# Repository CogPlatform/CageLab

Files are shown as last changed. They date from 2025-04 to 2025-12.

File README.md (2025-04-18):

---
title: CageLab
author: Ian Max Andolina
---

# Table of Contents

1. [Introduction](#introduction)
1. [Installation](#installation)
1. [Dependencies](#dependencies)
1. [Usage](#usage)
1. [Parts List](#parts-list)
1. [Architecture](#architecture)
1. [Contributing](#contributing)
1. [License](#license)

# Introduction

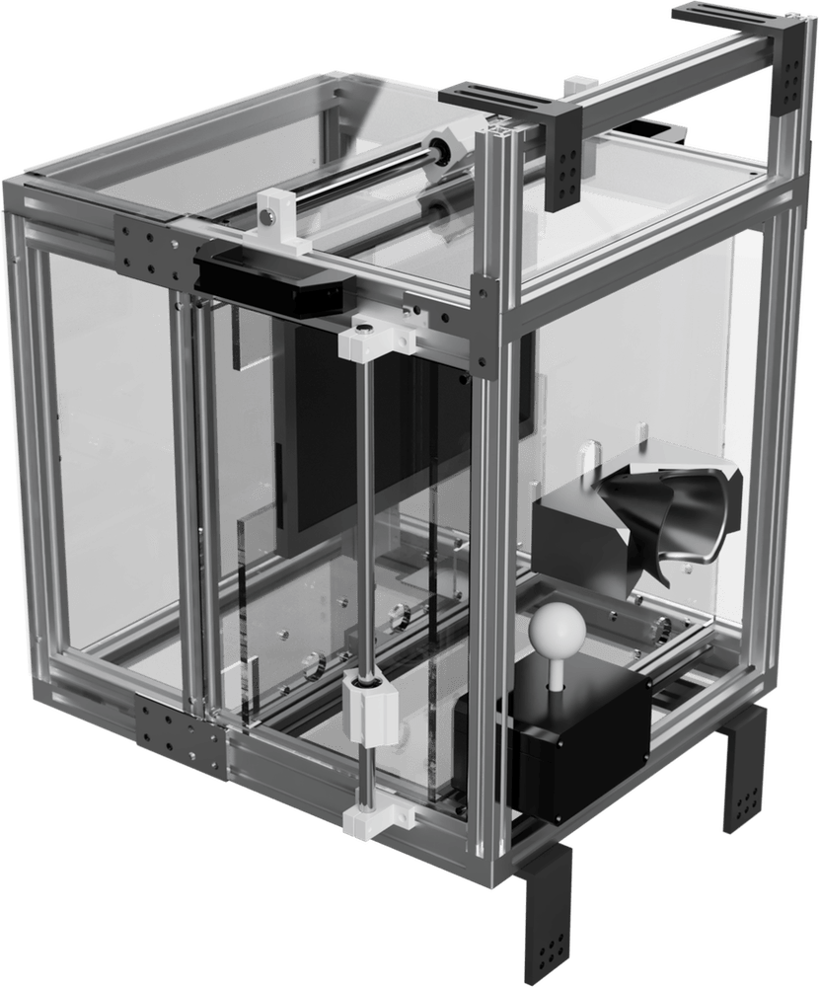
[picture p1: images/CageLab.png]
CageLab Render with Eyetracking and Joystick modules attached


CageLab is a low cost in-cage touchscreen training device that prioritises the following features:

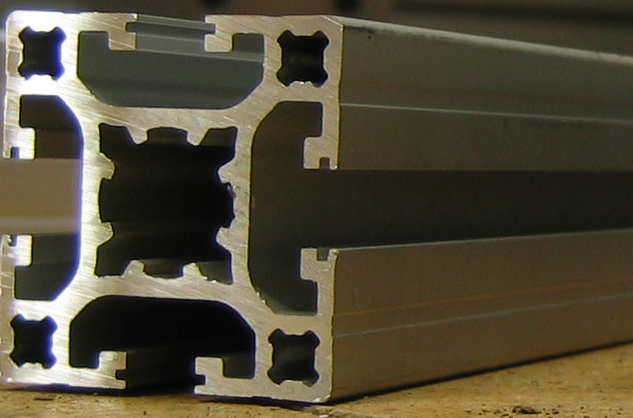
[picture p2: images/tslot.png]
1. **Customisable**: The device should be customisable to suit different facility needs. We employ a modular design using [ T-slot framing](https://en.wikipedia.org/wiki/T-slot_structural_framing) for the shell to allow for easy modification without needing a full workshop.
1. **Scalable**: Integration with the Alyx metadata pipeline ([International Brain Lab, 2023, Nature Methods](https://doi.org/10.1038/s41592-022-01742-6)) to allow for easy management of the data generated by multiple CageLab instances. Each device uploads behavioural data to a central server, which can be accessed and searched by the user through a web interface.
1. **Automatic Training**: Use behavioural shaping stages with an automated staircase to guide subjects to improved behavioural performance with less experimenter intervention.
1. **Low Cost**: CageLab should be affordable for most research labs. We aim to keep the total cost of the device below $400.
1. **Single-enclosure & Battery Operated**: Many animal facilities do not have accesible power outlets near animal housing, or do not want cables or extra trolleys. The device should be self-contained and battery operated. We added a small UPS to enable hot-swapping of batteries.
1. **Open Source**: The device software should be open source and easy to contribute to.
1. **Common Software Path**: The device should be easy to use and maintain; we use [PsychToolbox (PTB)](https://psychtoolbox.org) for easy integration with existing code common in most labs where PTB is prevalent. PTB offers best-in-class experiment timing and a wide range of specialised hardware support.
1. **Modular**: We have the following modules to use with the device:
   - **Fluid Pump**: Peristaltic pump, HID interface and costs about $10.
   - **Food Dispenser**: A pellet dispenser using an arduino driver.
   - **Camera**: A camera to record the animal's behaviour and stream it over the network.
   - **Speaker**: A speaker to play sounds.
1. **Remote Control**: The device must be controllable remotely. We use the fast moonlight remote desktop protocol and server + client protocols where useful.

# Installation and Setup

## Multi-Cage Setup

CageLab is designed to be used in a multi-cage setup. Each CageLab instance is connected to a central Alyz server that manages the data generated by each device. The server is accessible through a web interface that allows the user to search and download the data generated by each device. The experiment control software is run on a remote desktop that is connected to the device through the ZeroMQ client server protocol. The remote desktop allows the user to control the device from a distance and monitor the animal's behaviour through a camera that is connected to the device.

CageLab Multi-Cage Setup

## Hardware

## Software

You need Octave / MATLAB, PTB and the [opticka toolbox](https://github.com/iandol/opticka) installed as dependencies. For remote desktop, you need to install moonlight on the device and the client.

# Dependencies

- [matmoteGO](https://github.com/Ccccraz/matmoteGO.git)
- [cogmote](https://github.com/Ccccraz/cogmote.git)
- [cogmoteGO](https://github.com/Ccccraz/cogmoteGO.git)
- [streaming](https://github.com/Ccccraz/cagelab_streaming.git) Construction in progress
- [PTBSimia](https://github.com/Ccccraz/PTBSimia.git)

# Parts List

# Architecture

## Power supply architecture

### Poe solution

In previous version, we need to use power bank to power the device, but it is limiting the time of use. So we try to use poe to power the device.

> need poe IEEE 802.3bt and 802.3at protocol

> Expermimental feature!!!

> DC HUB was dangeous!!!

```mermaid
---
title: Power supply architecture with poe
---
graph LR
    subgraph Poe Router / Power Supply
    A
    F
    end
    A[IEEE 802.3bt terminal] -->|60 wt| B[poe++ splitter]
    A -->|Net connection| B
    B -->|24v| C[24v to 19v]
    B -->|Net connection| E[Mini PC]
    C -->|19v| D[DC UPS]
    D -->|19v| E
    F[IEEE 802.3at terminal] -->|30 wt| G[poe+ splitter]
    G -->|12v 2.5A MAX| H[DC HUB]
    H -->|12v| I[Pump]
    H -->|12v| J[Display]
    H -->|12v| K[speaker]
    H -->|12v| L[Sensors]
    F -->|Net connection| M@{ icon: "material-symbols:auto-delete"}
    subgraph payload
    E
    I
    J
    K
    L
    end
```

### Power bank solution

```mermaid
---
title: Power supply architecture with power bank
---
graph LR
    subgraph Power Bank / Power Supply
    A[PD power bank]
    E[DC power bank]
    end
    A[PD power bank] --> B[PD to dc]
    B -->|19v| C[DC UPS]
    C -->|19v| D[Mini PC]
    E[DC power bank] -->|12v| F[Pump]
    E -->|12v| G[Display]
    E -->|12v| H[Sensors]
    E -->|12v| I[speaker]
    subgraph payload
    D[Mini PC]
    F[Pump]
    G[Display]
    H[Sensors]
    I[speaker]
    end
```

# Contributing

Please feel free to open issues or pull requests. We are happy to help you get started with CageLab. We are also looking for collaborators to help us improve the device.

# License

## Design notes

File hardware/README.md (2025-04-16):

# Hardware

The hardware modules are designed to be modular and easy to assemble. We use T-slot aluminium framing for the shell to allow for easy modification without needing a full workshop. Both the fluid pump and joystick have a HID interface, allowing them to be used with any computer. The food dispenser is designed to be easy to clean and refill.

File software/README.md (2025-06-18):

# Software Frameworks

## Distributed Architecture
CageLab is designed to run on a distributed architecture, where each CageLab instance runs on a separate machine. This allows for flexibility in hardware selection and enables the use of multiple machines to run different experiments simultaneously. Each CageLab instance can be controlled remotely, allowing for easy management and monitoring of experiments.

Each CageLab runs a middleware called [cogmoteGO](https://github.com/Ccccraz/cogmoteGO), which establishes communication APIs to:

1. Relay command packets from a remote desktop machine to a local running PTB/MATLAB process (could be Octave, Python or any other experiment framework). The messages are JSON encoded and sent using a HTTP POST request and cogmoteGO forwards them over a local ZeroMQ REQ channel to the PTB/MATLAB process.
2. Broadacast data messages from PTB/MATLAB (or other experiment framework) that can be subscribed to by any number of remote machines.

We use the Opticka toolbox for the main experiment control, a high-level wrapper for PsychToolbox. A GUI called `CageLab.mlapp` is provided. The GUI is run on your desktop machine and will send the experiment settings to the CageLab instance. The CageLab device runs a MATLAB service called `theConductor` that receives commands and orchestrates experiments. Each experiment protocol can be run either locally or remotely. We use another app, Puremote, to visualise the subject screen (streamed via mediamtx server), a video feed from the CageLab camera and to plot the broadcast data. 

## Software Components

- **Opticka**: A high-level wrapper for PsychToolbox, used for experiment control.
- **cogmoteGO**: Middleware for communication between remote desktop and local CageLab instance.
- **theConductor**: A MATLAB service that orchestrates experiments on the CageLab instance. Runs CageLab behavioural tasks.
- **CageLab.mlapp**: A GUI for configuring and controlling experiments on the CageLab instance, run on a remote computer.
- **Puremote**: An app for visualising the subject display, video feed from the CageLab camera, and plotting the broadcast data.

## Viewing the Opticka experiment log remotely

**theConductor** is run vis `systemd` and logs are therefore readable using `journalctl`. You can read the log remotely using ssh to login to the Cagelab instance and then running `journalctl --user -f -u theConductor`.

## Data pipeline

We use the [International Brain Lab](https://doi.org/10.1038/s41592-022-01742-6) metadata pipeline to manage the data generated by CageLab instances, which opticka supports without any other dependencies. 

## Remote access

We use Zerotier VPN, SSH and NoMachine or [moonlight](https://moonlight-stream.org) for remote control of the device.

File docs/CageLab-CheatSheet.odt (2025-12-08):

I3 Window Manager: Press WIN to show task bar. WIN+ENTER to open a new terminal. Press WIN+[d] to run a program. Press WIN+SHIFT+[q] to close a window. Press WIN+SHIFT+[e] to exit i3. To move desktop WIN+[1]-[9]. To move an app to a new desktop WIN+Shift+[1]-[9]. To toggle windows as tabs/accordion WIN+Shift+[,] as toggle V/H tiles WIN+Shift+[/] and to float a window WIN+Shift+[.] To resize a floating window WIN+RMB and move it WIN+LMB. To move a window to scrachpad WIN+Shift+[+] and show/hide it WIN+[+].

COMMAND | PURPOSE | NOTES
lsusb | Show list of all connected USB devices
xinput list | Show list of all input devices including touch screen. | Find screen and use ID number to enable / disable
xinput enable # xinput disable # | Enable or disable touch screen or other device, # is the ID number you see in the list
toggleInput enable “ILITEK-TP” toggleInput disable “ILITEK-TP” | Enable or disable touch screen using the touchscreen name
cagelab-reset-code.sh | git reset –hard and pull al repos.
cagelab-reset.sh | Restart cogmoteGO and MATLAB theConductor
cagelab-reset-OBS.sh | Restart mediamtx and OBS
cagelab-stop.sh | Stop all cagelab services
cagelab-start.sh | Start all cagelab services
cagelab-monitor.sh | Show CPU/GPU use alongside cogmoteGO and MATLAB logs
update | Update Code folders and essential software (needs internet)
cagepush -s remote folder | On the control computer push one/many local folders to one/many remote cagelab over the local network | Uses rsync
cagepull -s remote1 -s remote2 | On the control computer pull the data from multiple cagelab systems over local network. | Uses rsync
cagepush-files -s remote app | Push one/many files to one/many cagelab over the local network | Uses scp
`

CageLab Command Cheat Sheet

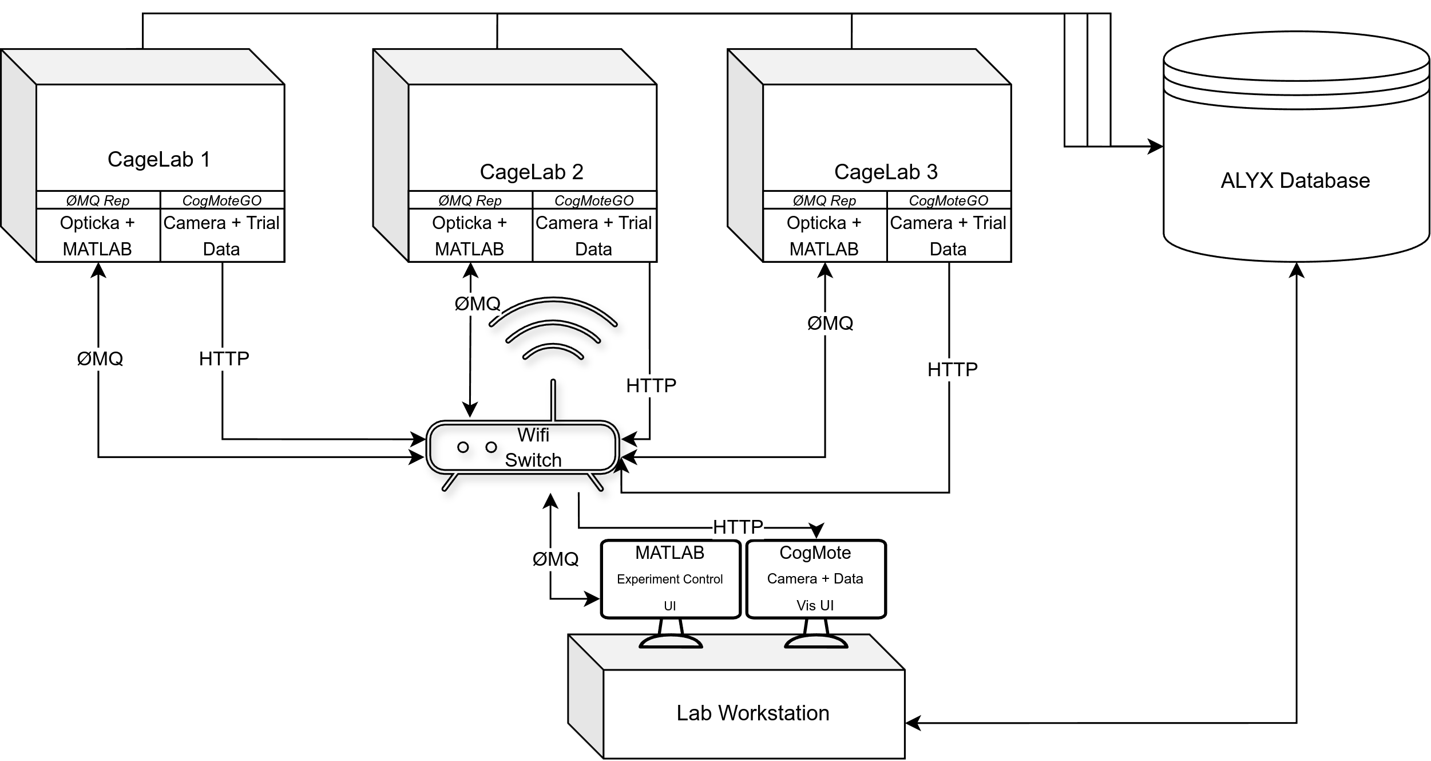
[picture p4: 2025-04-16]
images/CageLab-Network.png

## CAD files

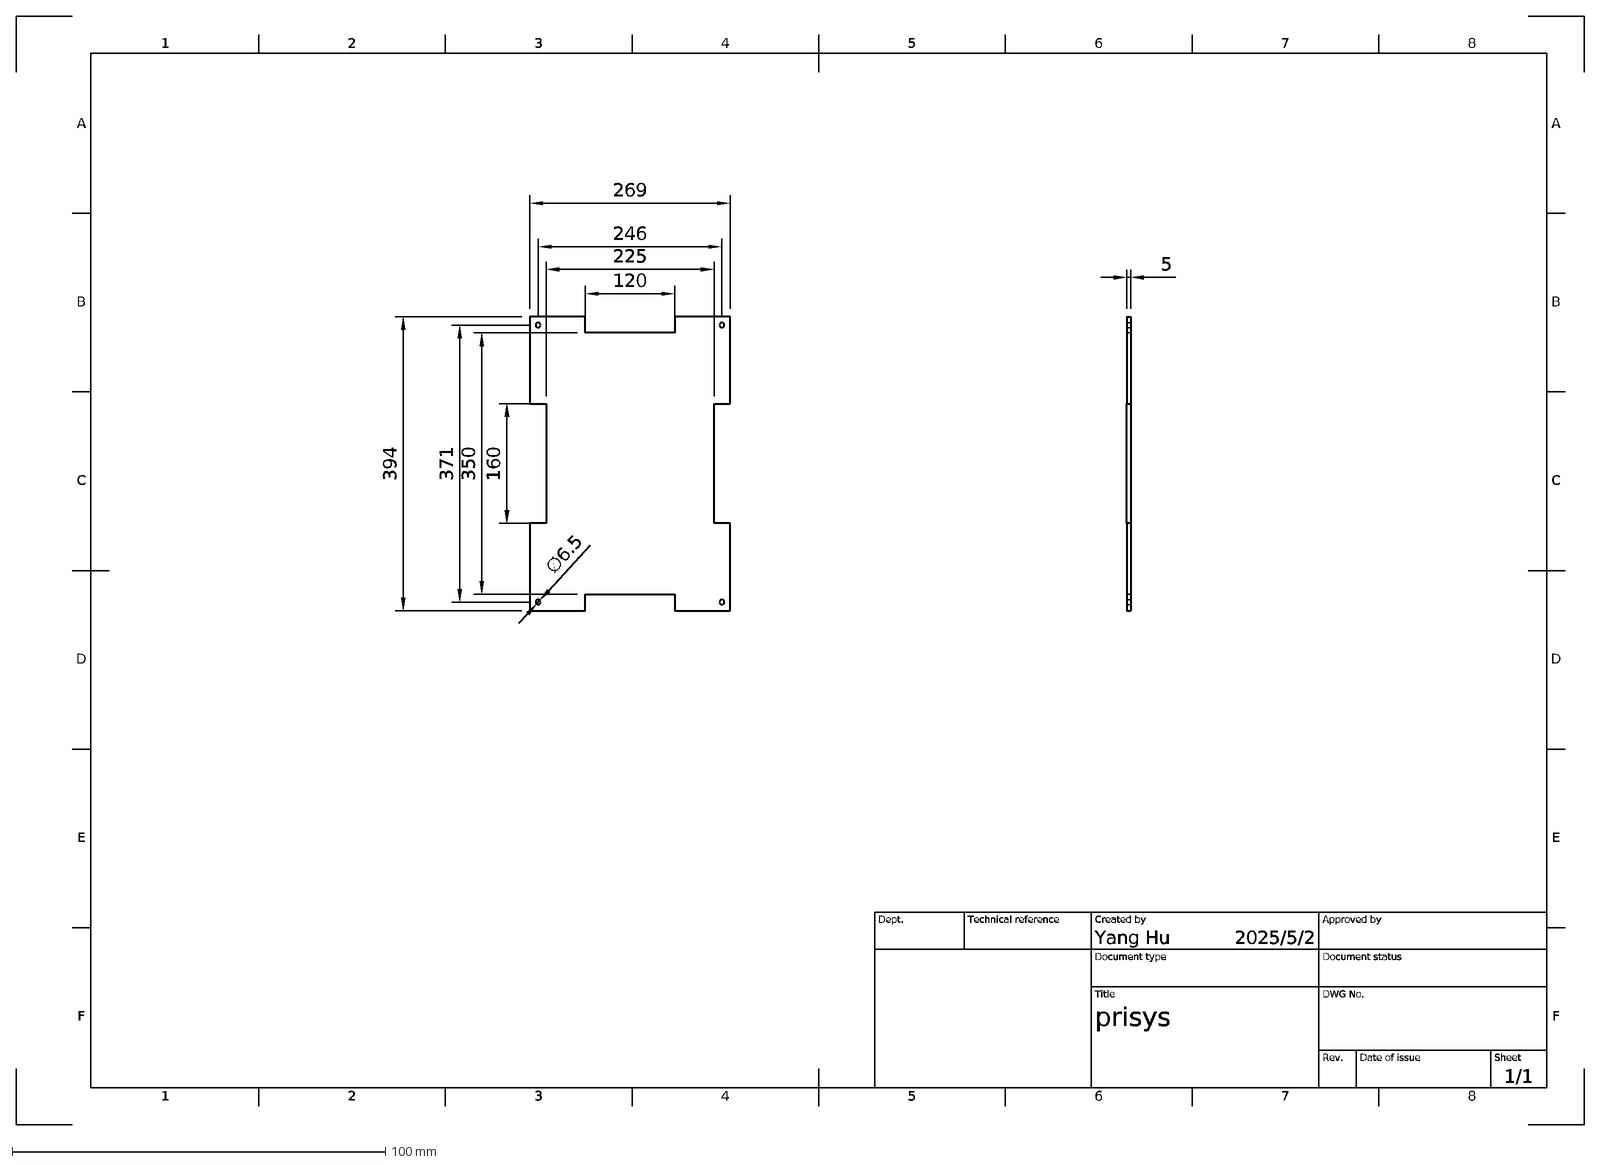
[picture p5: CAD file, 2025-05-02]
manufacture/plate/europe/core_back.dxf
1
A
2
3
4
5
6
7
8
B
C
D
E
F
2025/5/2
1/1
prisys
Yang Hu
Dept.
Technical reference
Created by
Approved by
Document type
Document status
Title
DWG No.
Rev.
Date of issue
Sheet
120
246
269
160
371
394
∅6.5
225
350

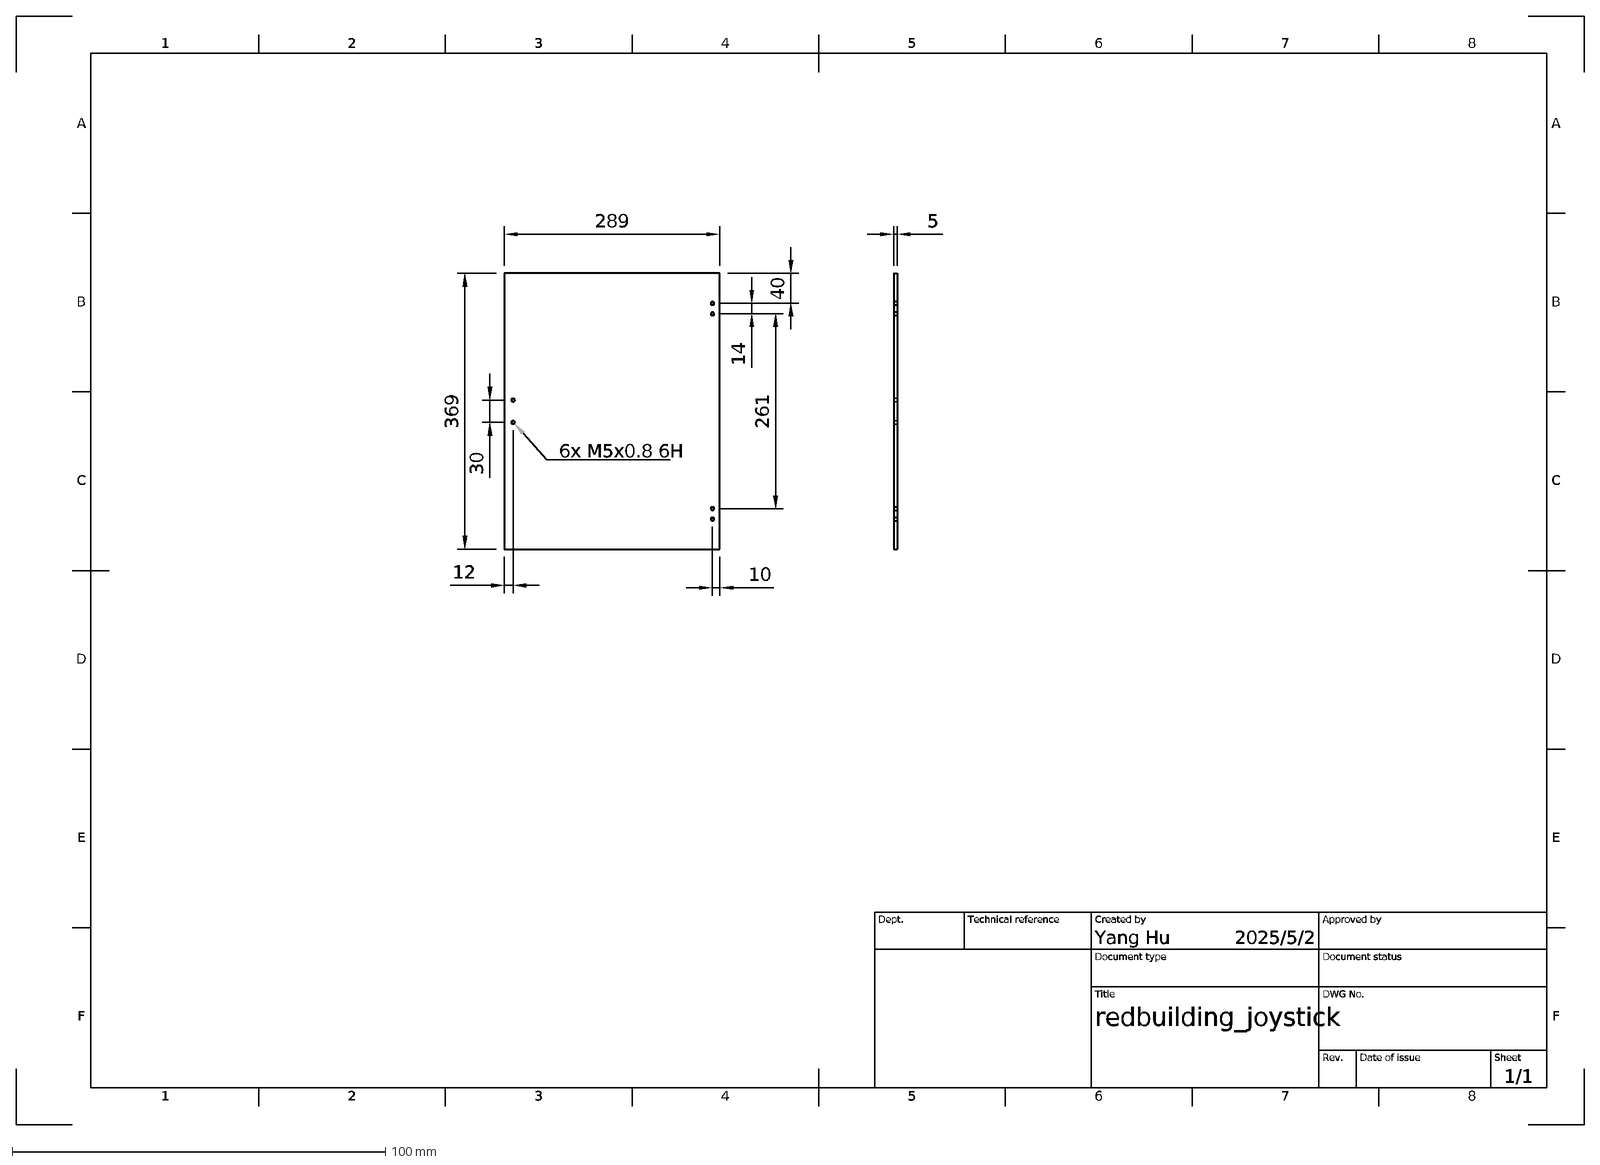
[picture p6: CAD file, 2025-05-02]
manufacture/plate/redbuilding/extra_back.dxf
1
A
2
3
4
5
6
7
8
B
C
D
E
F
2025/5/2
1/1
redbuilding_joystick
Yang Hu
Dept.
Technical reference
Created by
Approved by
Document type
Document status
Title
DWG No.
Rev.
Date of issue
Sheet
289
369
30
14
40
261
6x M5x0.8 6H
12
10

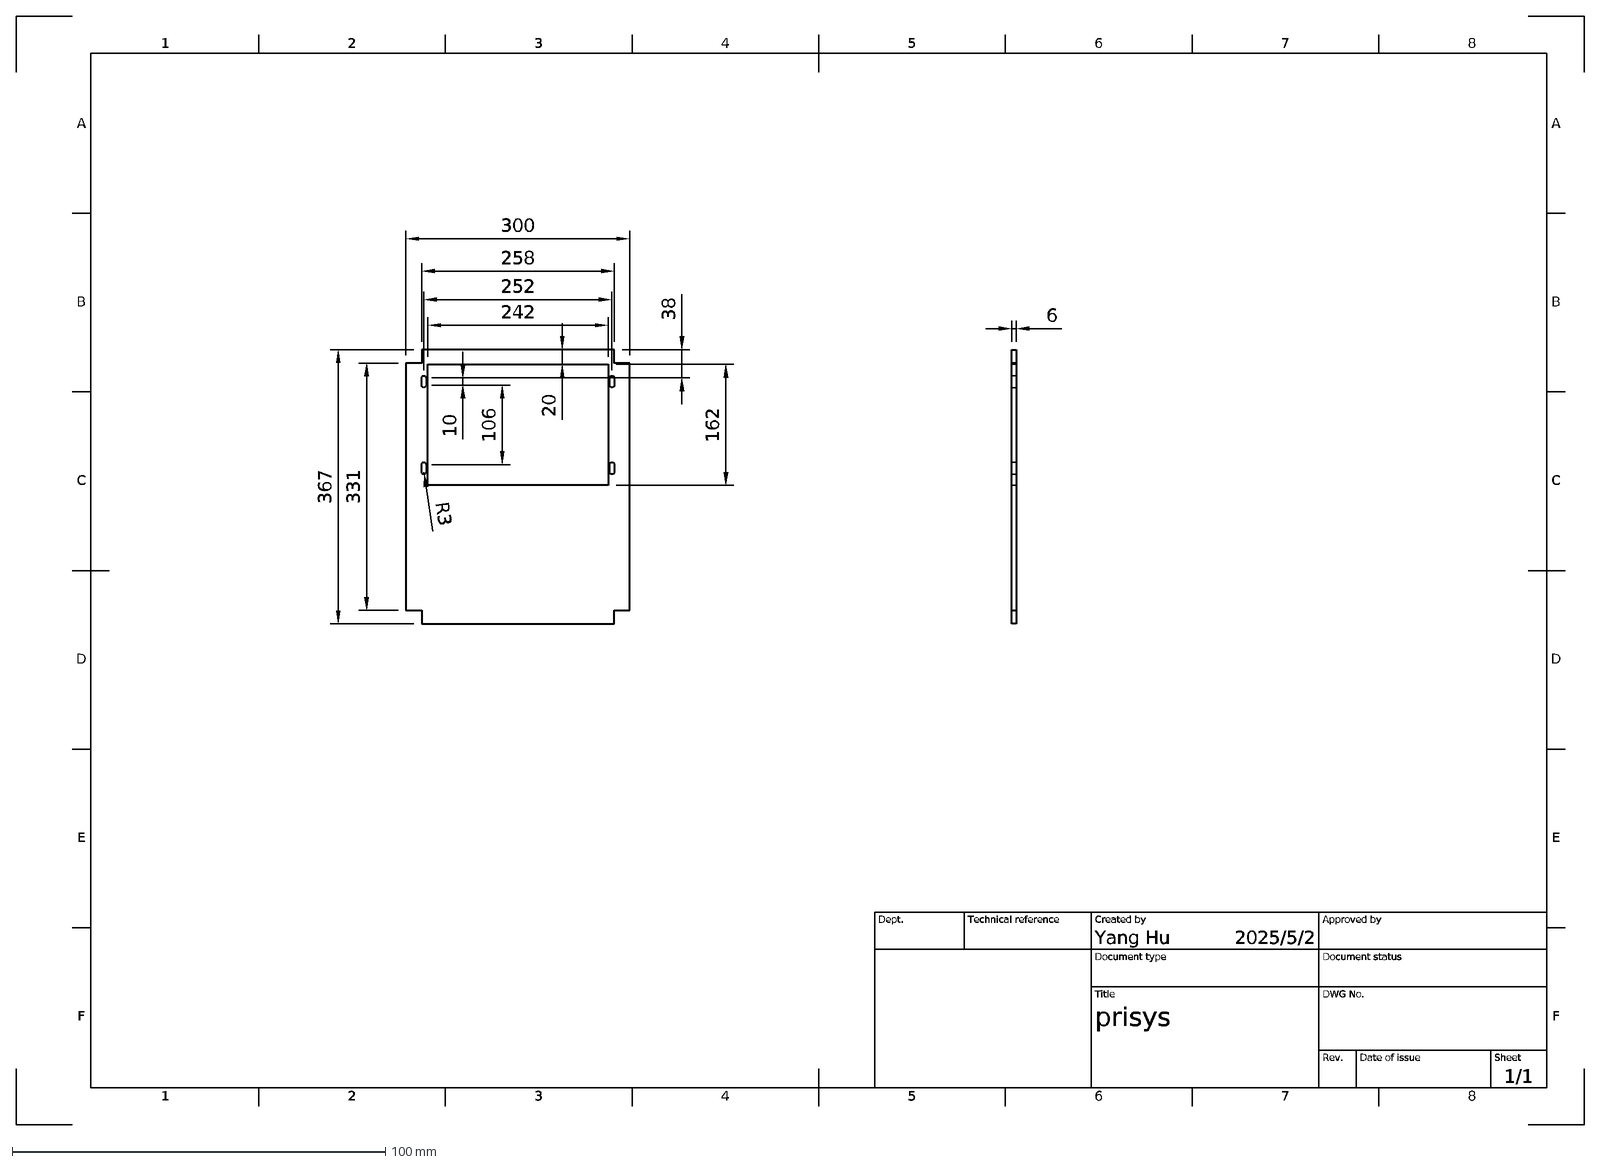
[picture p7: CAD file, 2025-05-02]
manufacture/plate/europe/core_display.dxf
1
A
2
3
4
5
6
7
8
B
C
D
E
F
2025/5/2
1/1
prisys
Yang Hu
Dept.
Technical reference
Created by
Approved by
Document type
Document status
Title
DWG No.
Rev.
Date of issue
Sheet
242
252
258
300
331
367
10
106
38
162
R3
20

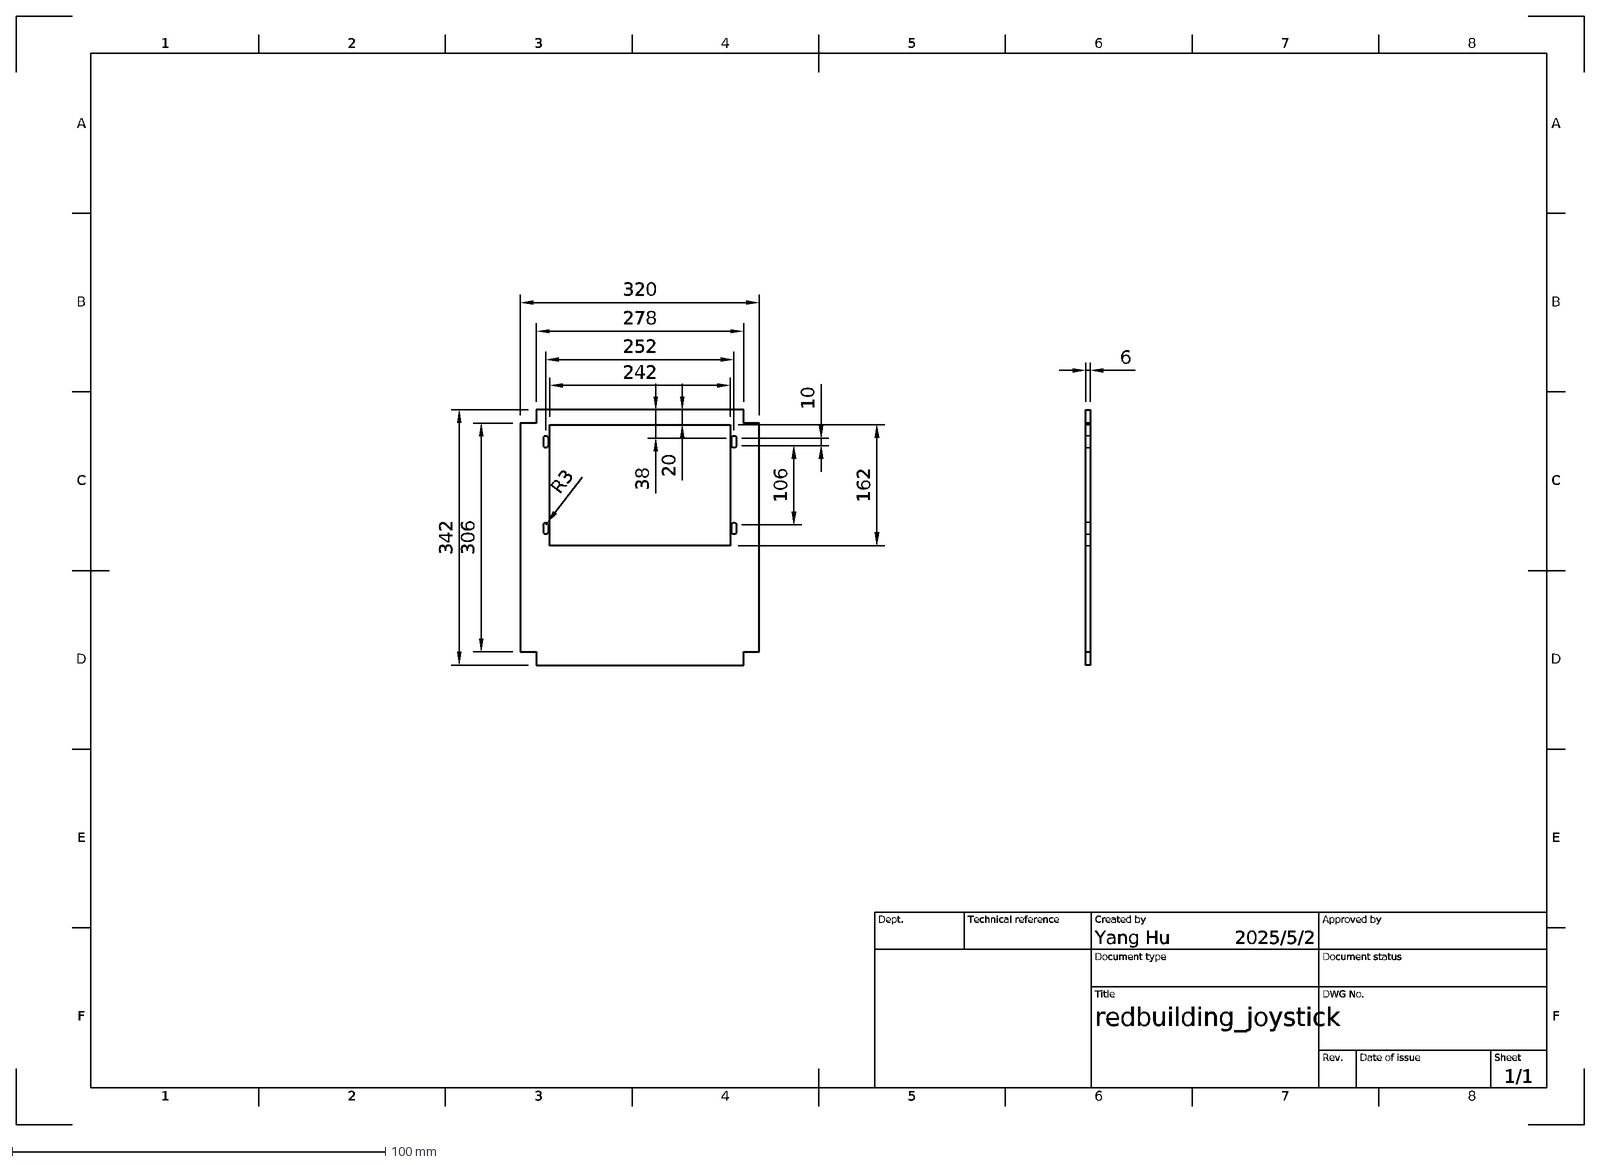
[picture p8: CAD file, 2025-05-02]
manufacture/plate/redbuilding/core_display.dxf
1
A
2
3
4
5
6
7
8
B
C
D
E
F
2025/5/2
1/1
redbuilding_joystick
Yang Hu
Dept.
Technical reference
Created by
Approved by
Document type
Document status
Title
DWG No.
Rev.
Date of issue
Sheet
242
252
278
320
306
342
106
10
162
R3
38
20

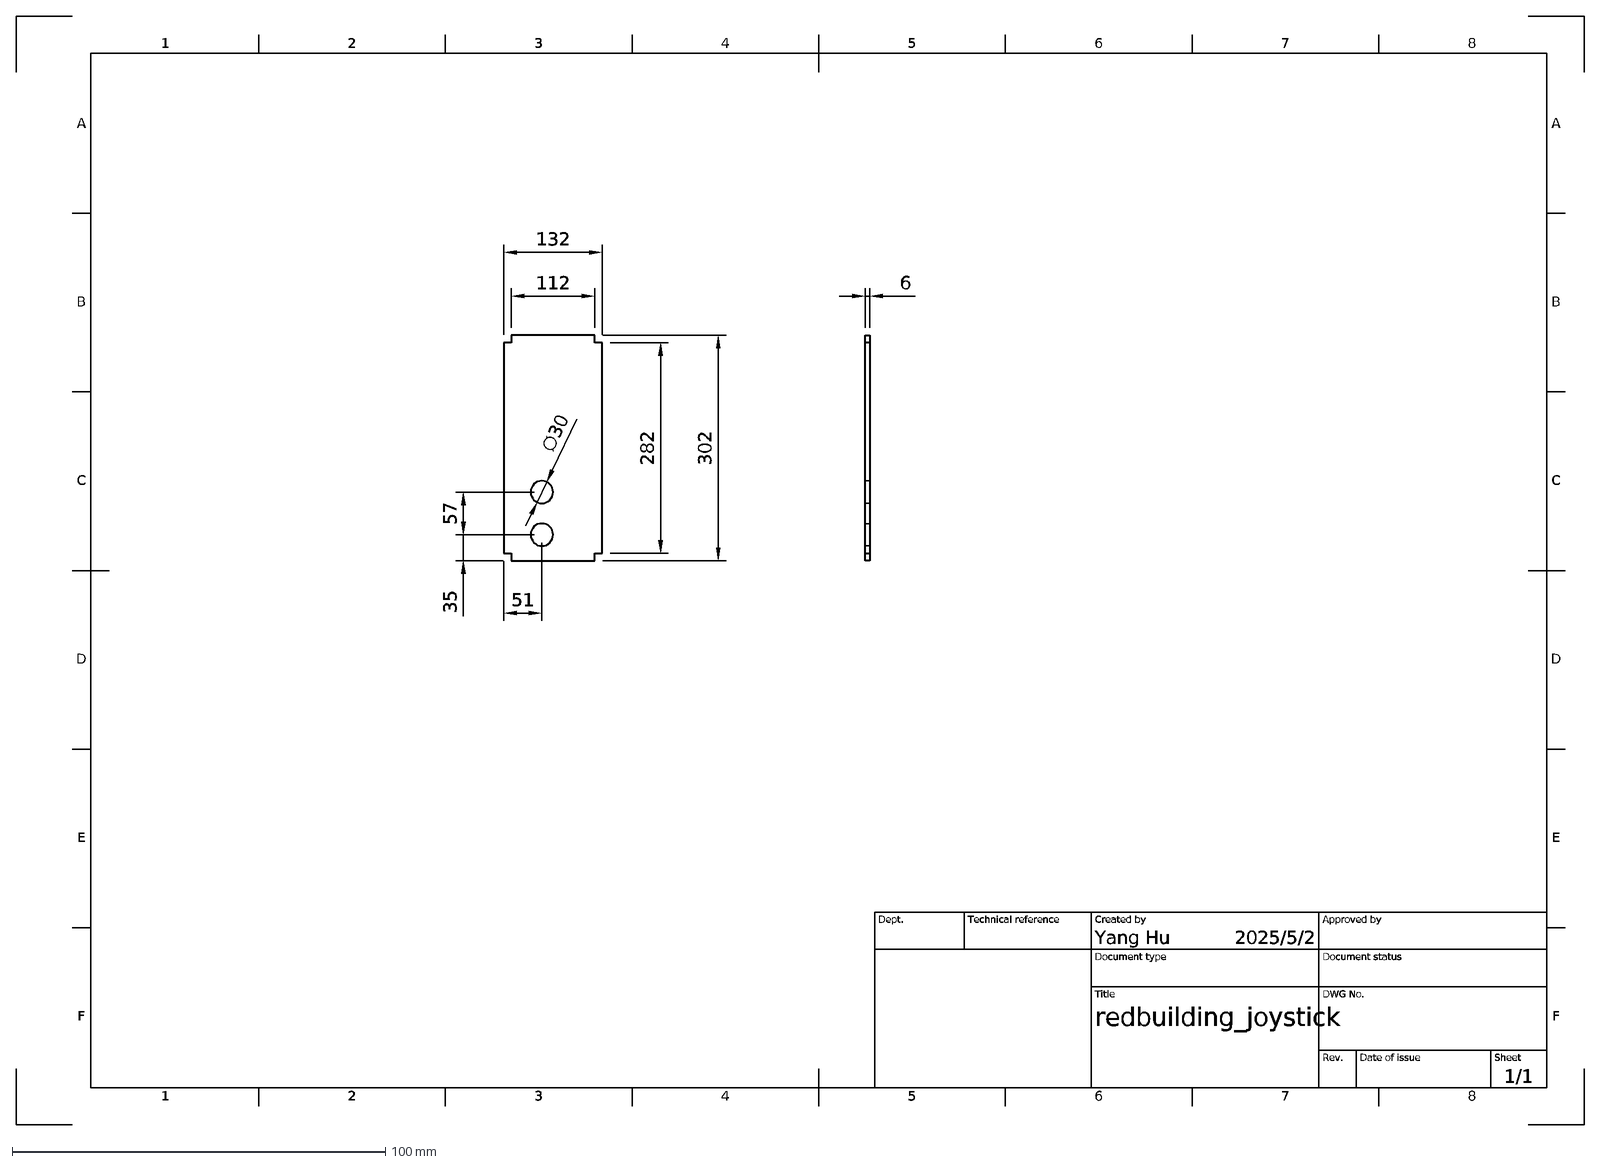
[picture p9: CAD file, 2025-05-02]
manufacture/plate/europe/extra_bottom.dxf
1
A
2
3
4
5
6
7
8
B
C
D
E
F
2025/5/2
1/1
redbuilding_joystick
Yang Hu
Dept.
Technical reference
Created by
Approved by
Document type
Document status
Title
DWG No.
Rev.
Date of issue
Sheet
112
132
57
35
282
302
∅30
51

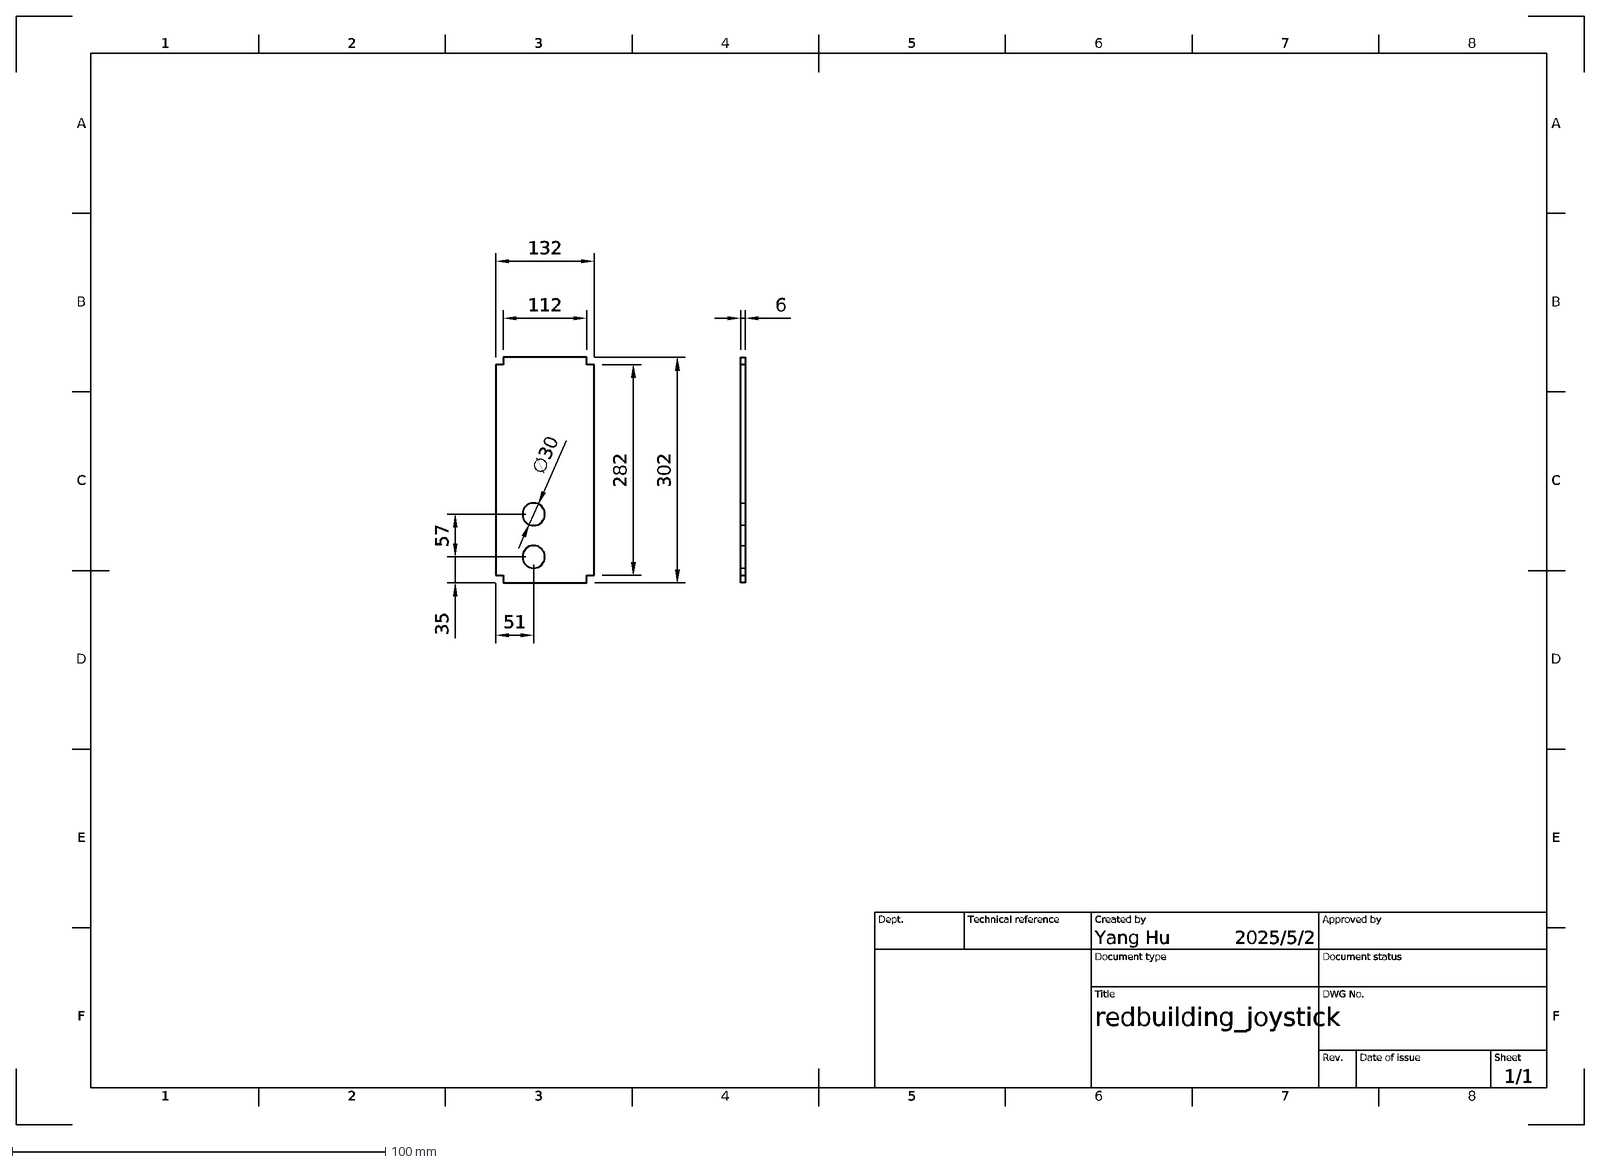
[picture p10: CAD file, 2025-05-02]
manufacture/plate/redbuilding/extra_bottom.dxf
1
A
2
3
4
5
6
7
8
B
C
D
E
F
2025/5/2
1/1
redbuilding_joystick
Yang Hu
Dept.
Technical reference
Created by
Approved by
Document type
Document status
Title
DWG No.
Rev.
Date of issue
Sheet
112
132
282
302
35
57
∅30
51

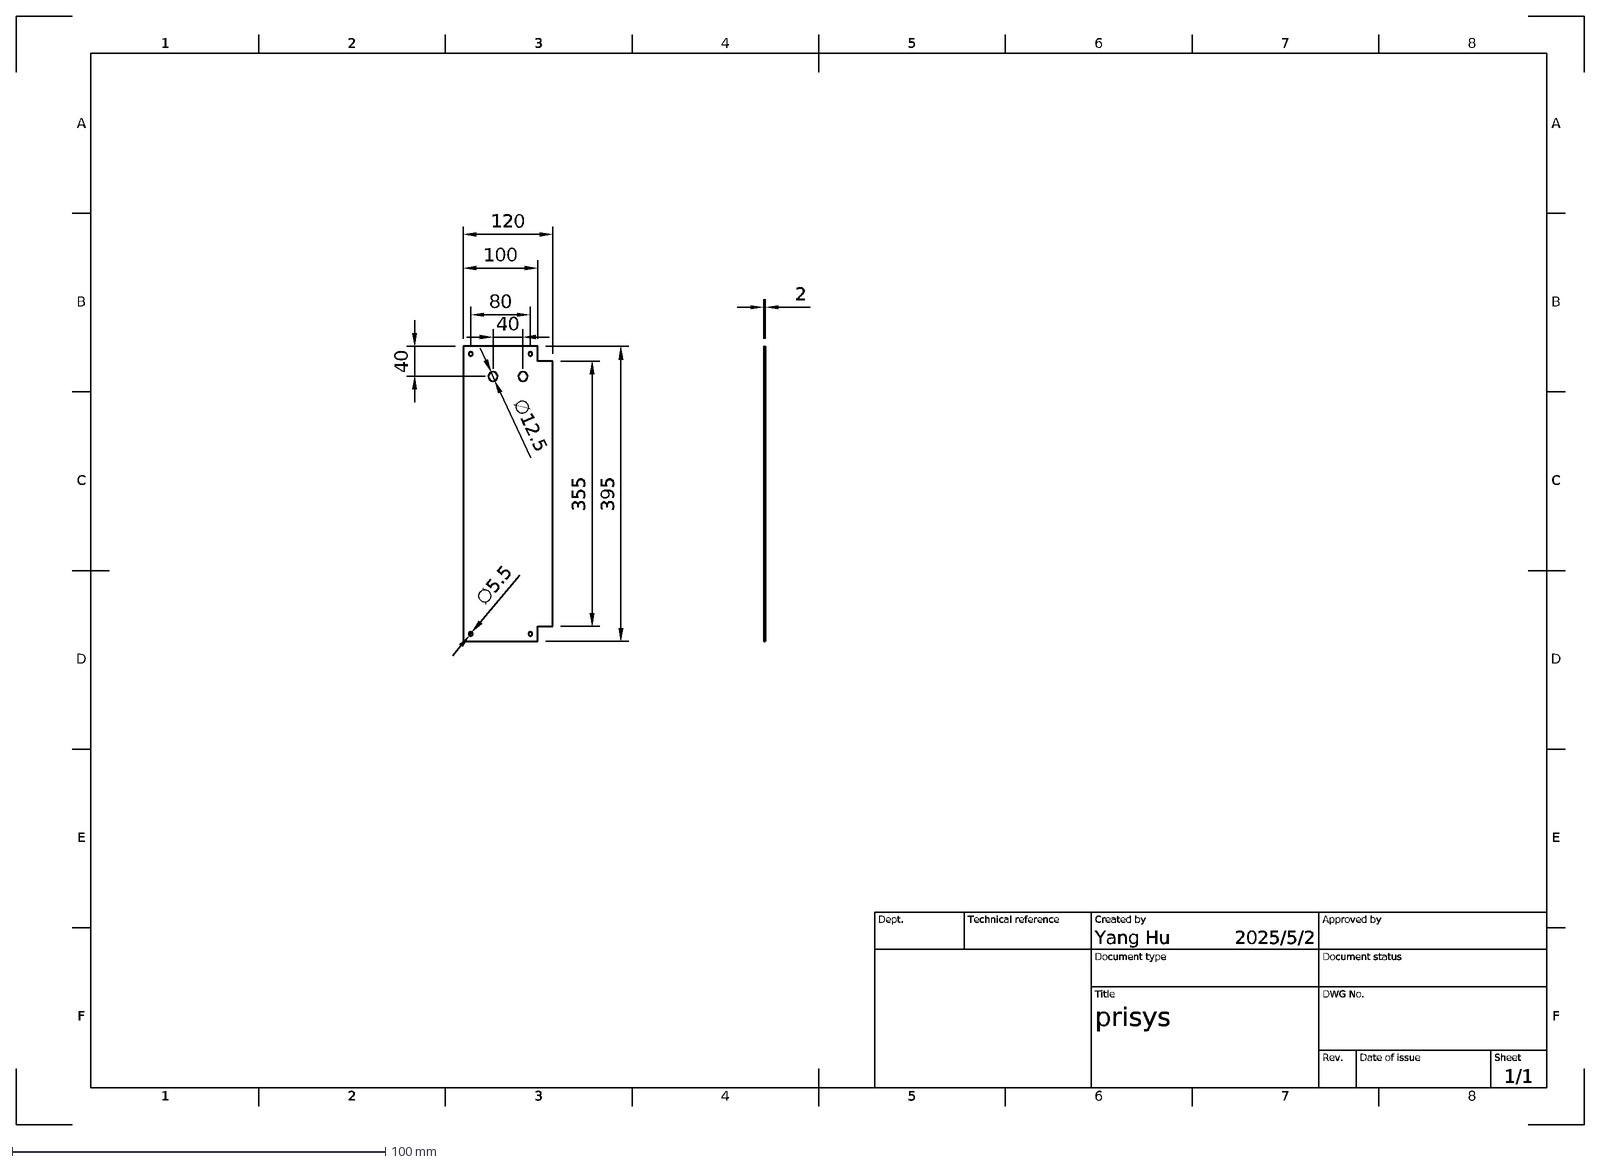
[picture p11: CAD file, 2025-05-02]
manufacture/plate/europe/extra_side.dxf
1
A
2
3
4
5
6
7
8
B
C
D
E
F
2025/5/2
1/1
prisys
Yang Hu
Dept.
Technical reference
Created by
Approved by
Document type
Document status
Title
DWG No.
Rev.
Date of issue
Sheet
40
80
100
120
355
395
∅5.5
∅12.5

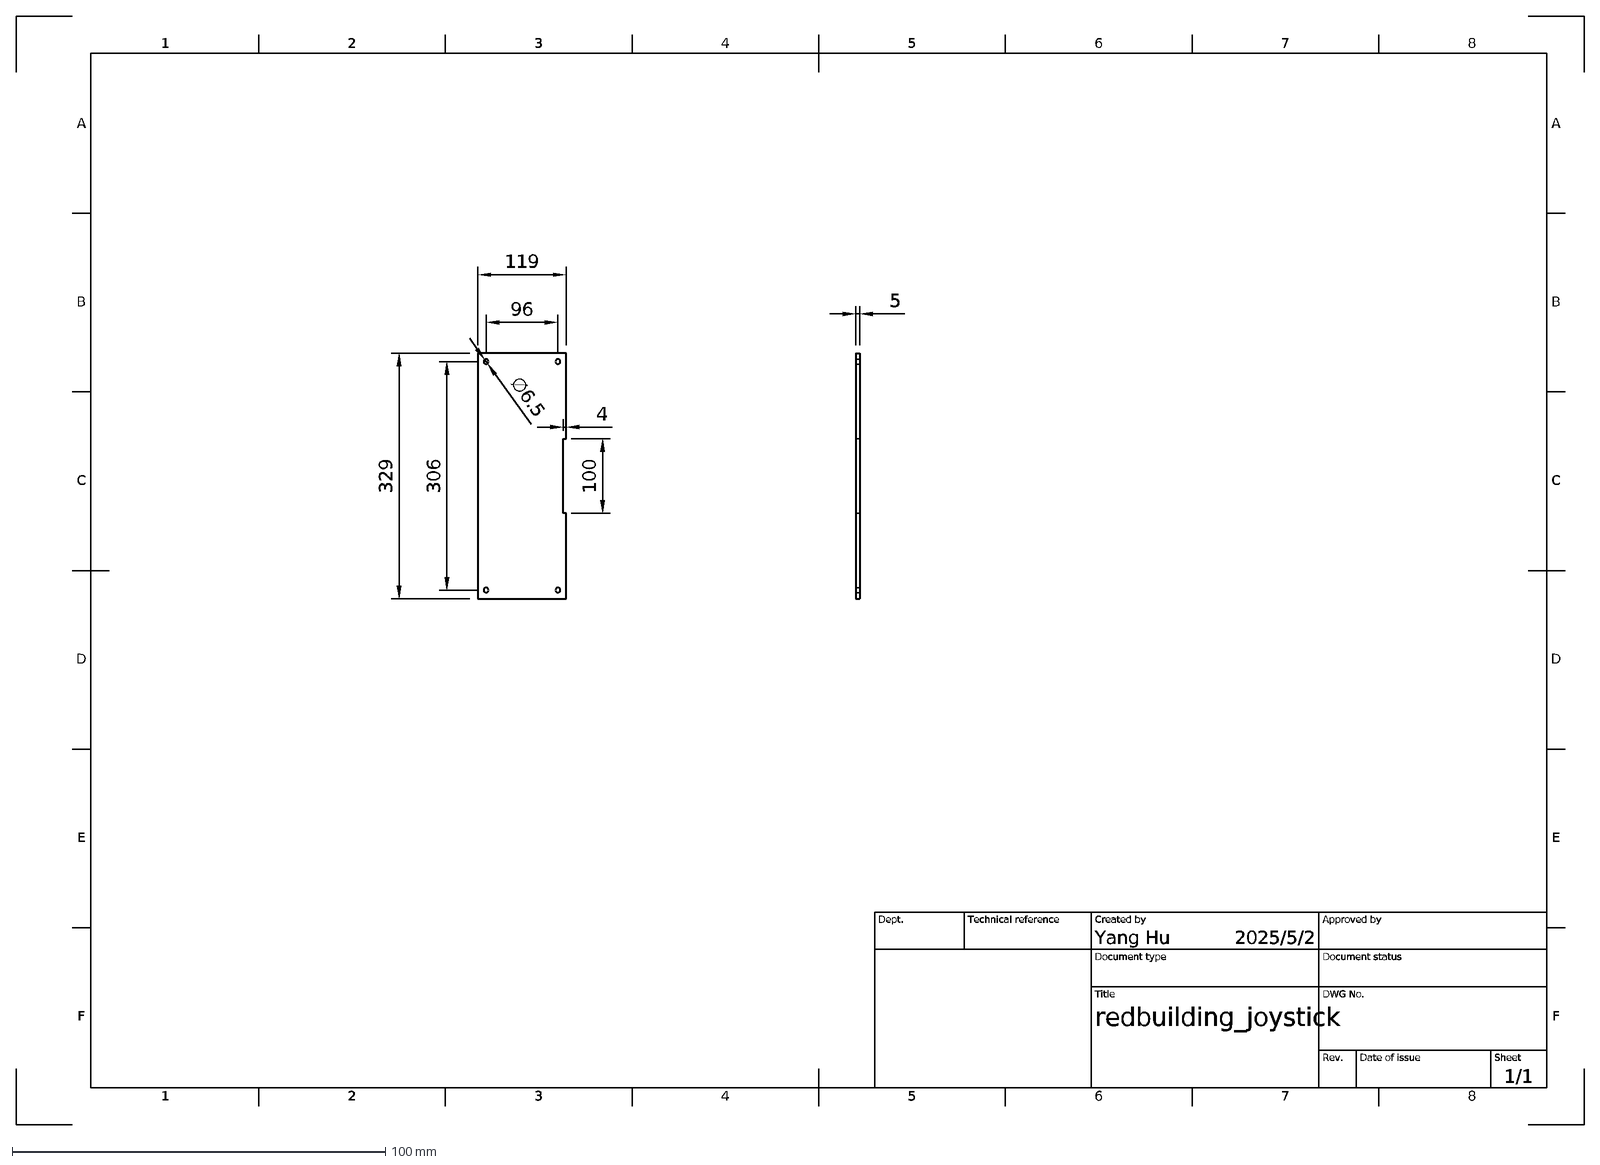
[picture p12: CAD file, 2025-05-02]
manufacture/plate/redbuilding/core_side.dxf
1
A
2
3
4
5
6
7
8
B
C
D
E
F
2025/5/2
1/1
redbuilding_joystick
Yang Hu
Dept.
Technical reference
Created by
Approved by
Document type
Document status
Title
DWG No.
Rev.
Date of issue
Sheet
96
119
306
329
100
∅6.5

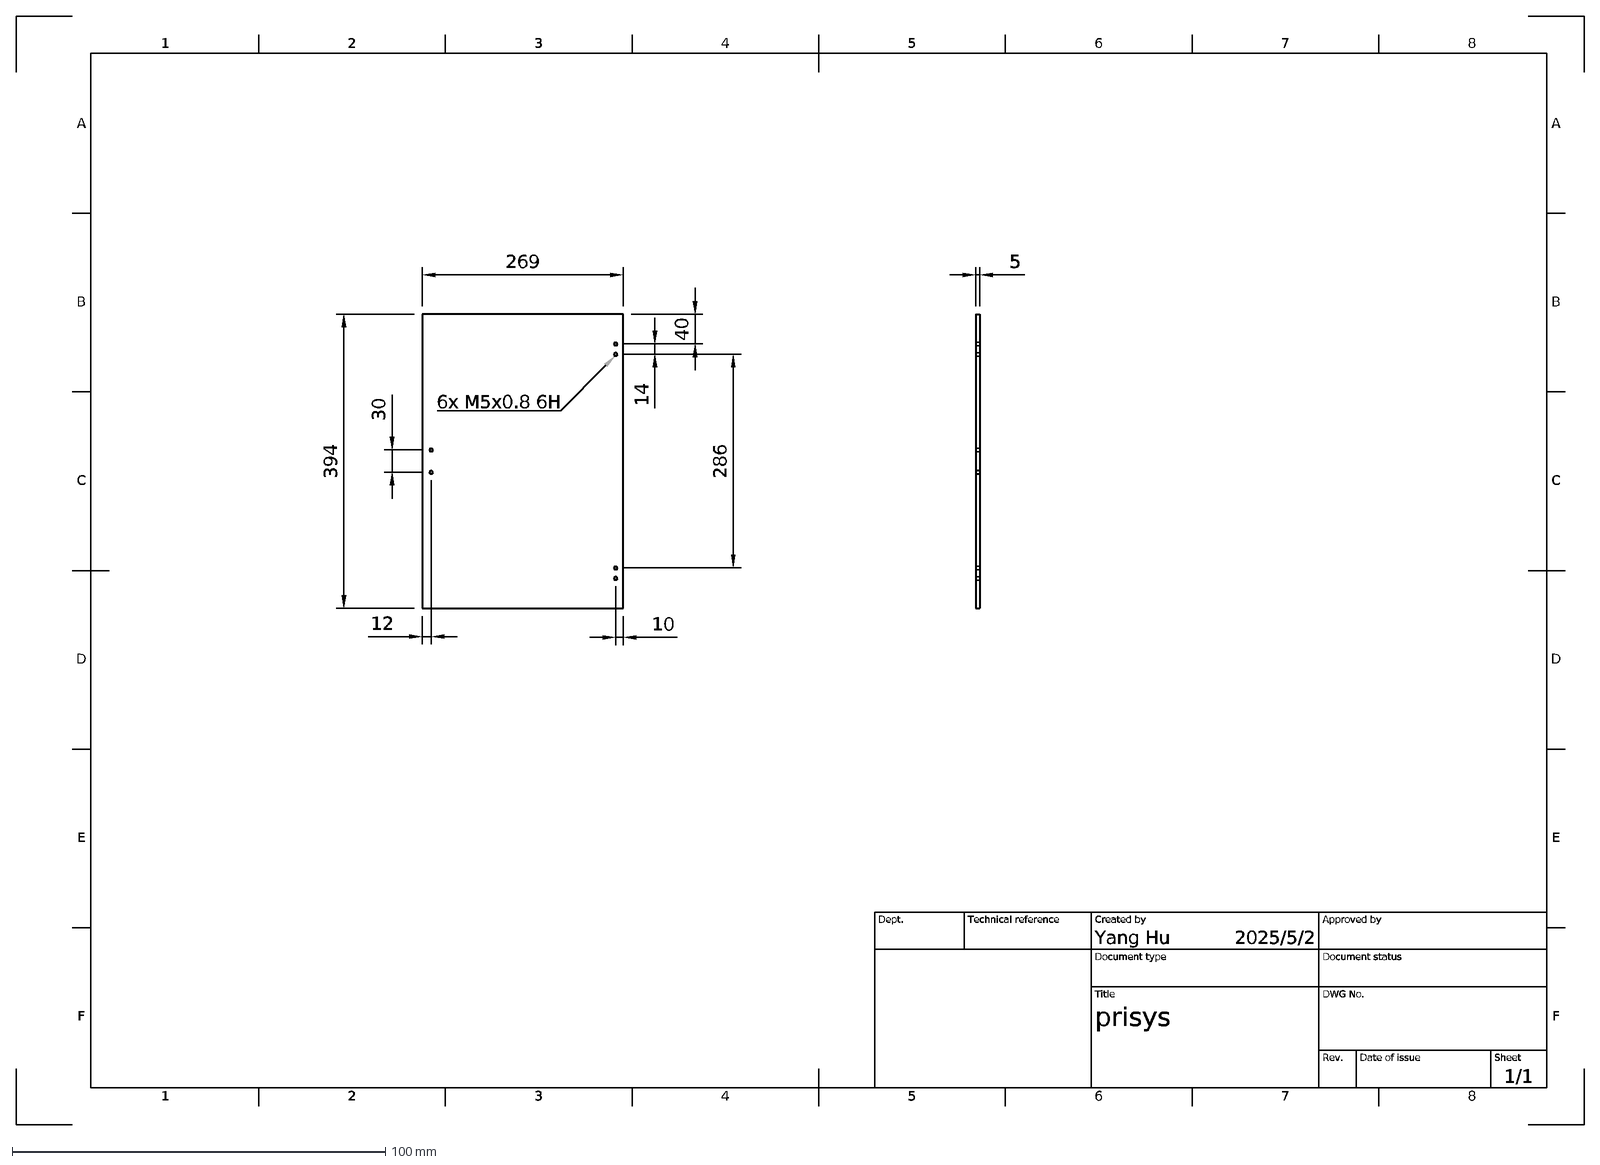
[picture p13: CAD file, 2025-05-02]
manufacture/plate/europe/extra_back.dxf
1
A
2
3
4
5
6
7
8
B
C
D
E
F
2025/5/2
1/1
prisys
Yang Hu
Dept.
Technical reference
Created by
Approved by
Document type
Document status
Title
DWG No.
Rev.
Date of issue
Sheet
269
14
40
286
30
394
6x M5x0.8 6H
12
10

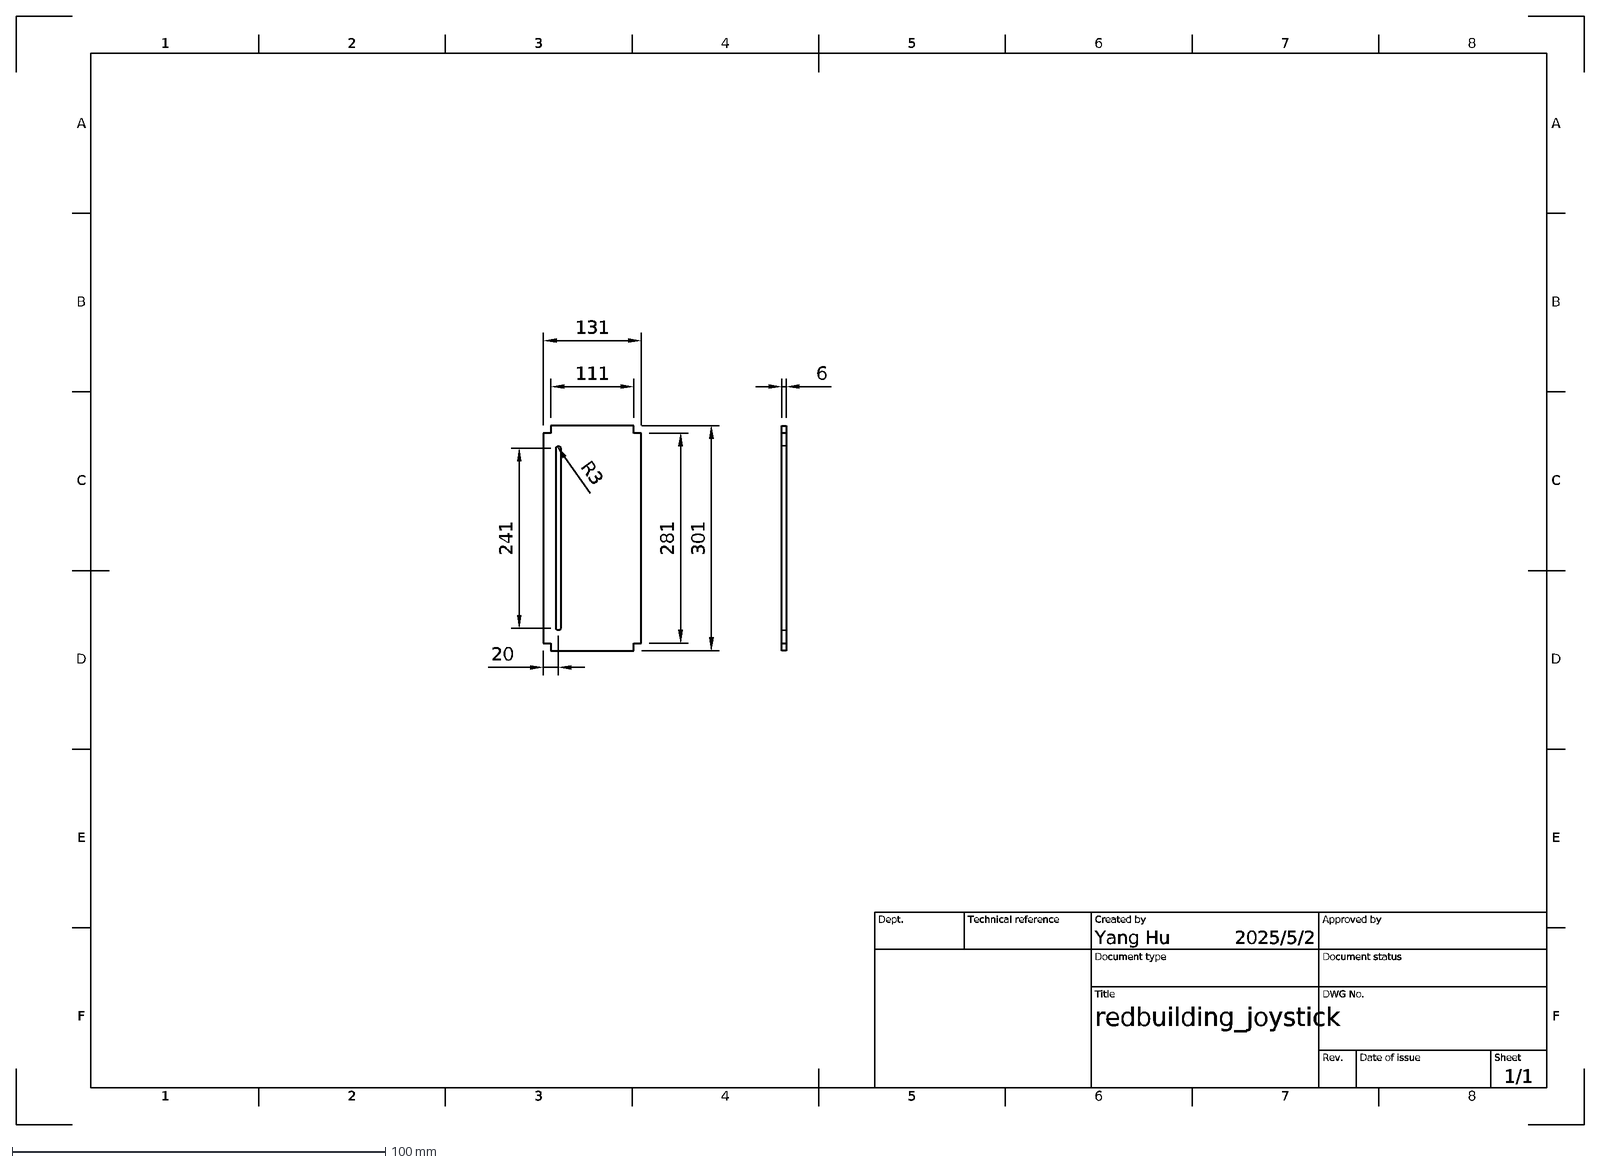
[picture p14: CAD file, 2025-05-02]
manufacture/plate/redbuilding/core_bottom.dxf
1
A
2
3
4
5
6
7
8
B
C
D
E
F
2025/5/2
1/1
redbuilding_joystick
Yang Hu
Dept.
Technical reference
Created by
Approved by
Document type
Document status
Title
DWG No.
Rev.
Date of issue
Sheet
111
131
241
R3
281
301
20

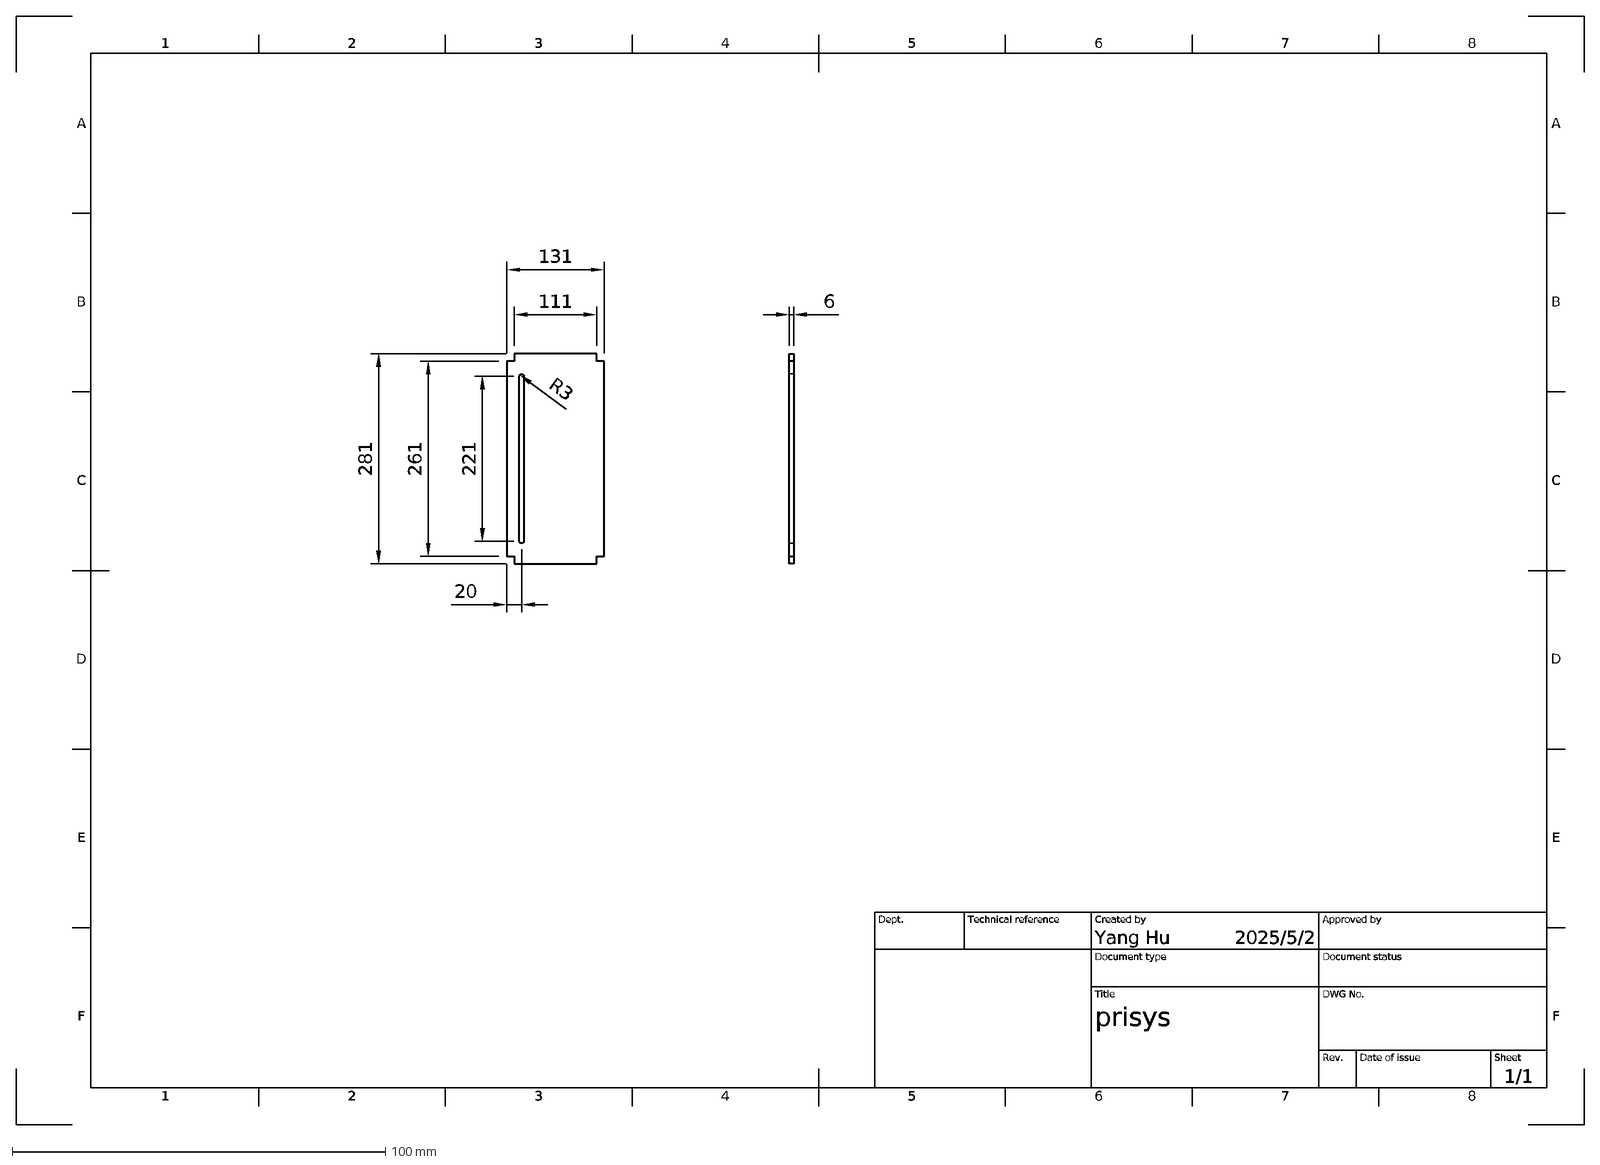
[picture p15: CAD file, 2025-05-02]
manufacture/plate/europe/core_bottom.dxf
1
A
2
3
4
5
6
7
8
B
C
D
E
F
2025/5/2
1/1
prisys
Yang Hu
Dept.
Technical reference
Created by
Approved by
Document type
Document status
Title
DWG No.
Rev.
Date of issue
Sheet
111
131
221
261
281
R3
20

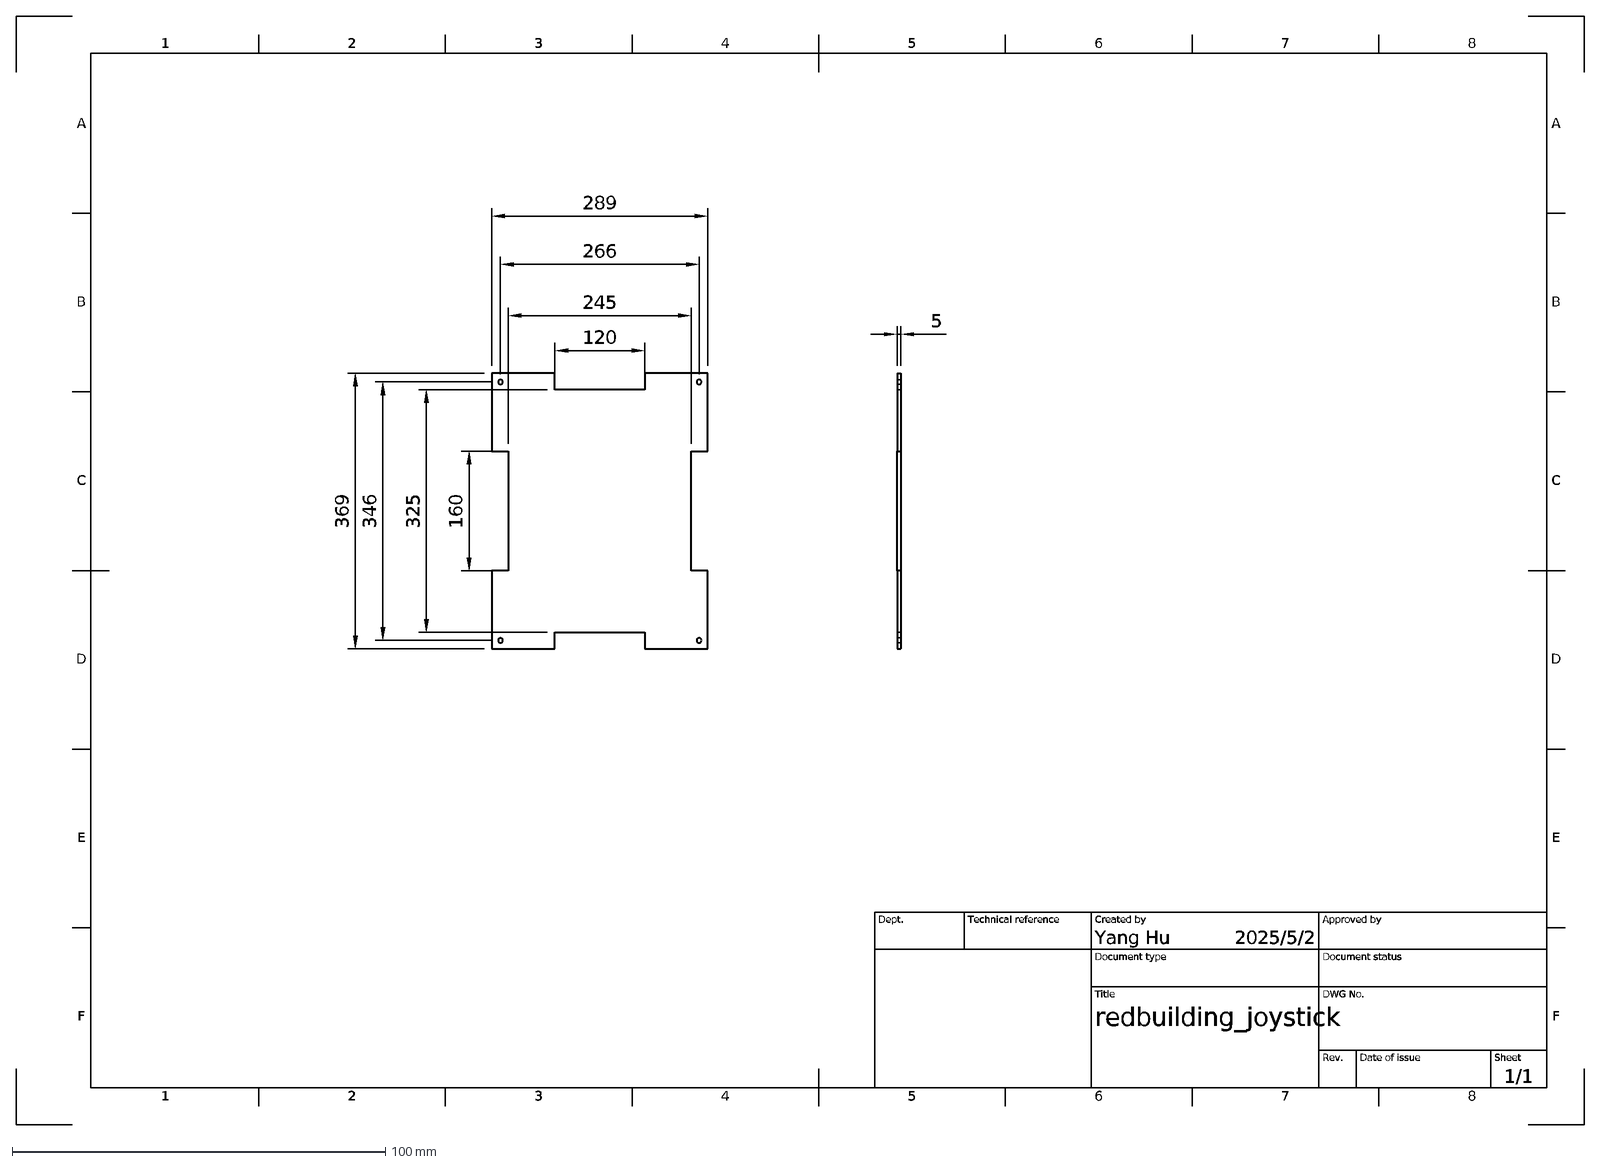
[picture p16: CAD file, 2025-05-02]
manufacture/plate/redbuilding/core_back.dxf
1
A
2
3
4
5
6
7
8
B
C
D
E
F
2025/5/2
1/1
redbuilding_joystick
Yang Hu
Dept.
Technical reference
Created by
Approved by
Document type
Document status
Title
DWG No.
Rev.
Date of issue
Sheet
120
245
266
289
160
325
346
369

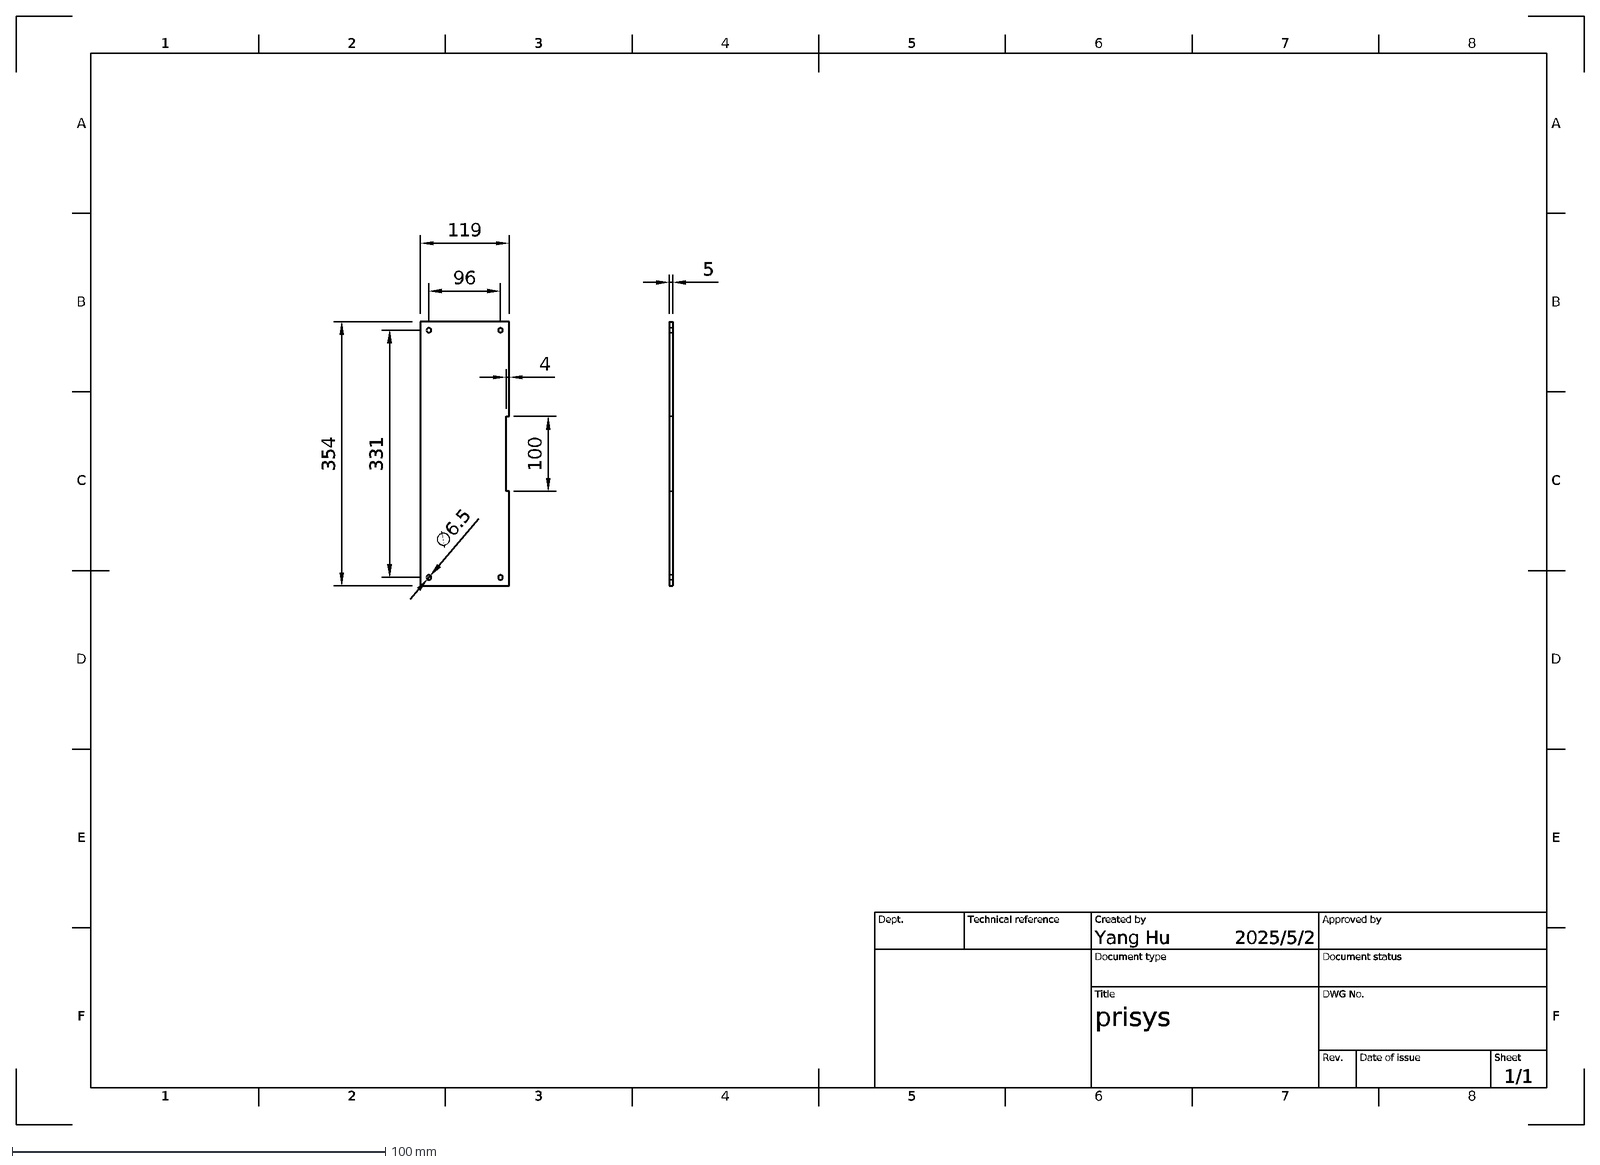
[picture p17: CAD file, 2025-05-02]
manufacture/plate/europe/core_side.dxf
1
A
2
3
4
5
6
7
8
B
C
D
E
F
2025/5/2
1/1
prisys
Yang Hu
Dept.
Technical reference
Created by
Approved by
Document type
Document status
Title
DWG No.
Rev.
Date of issue
Sheet
96
119
331
354
100
∅6.5

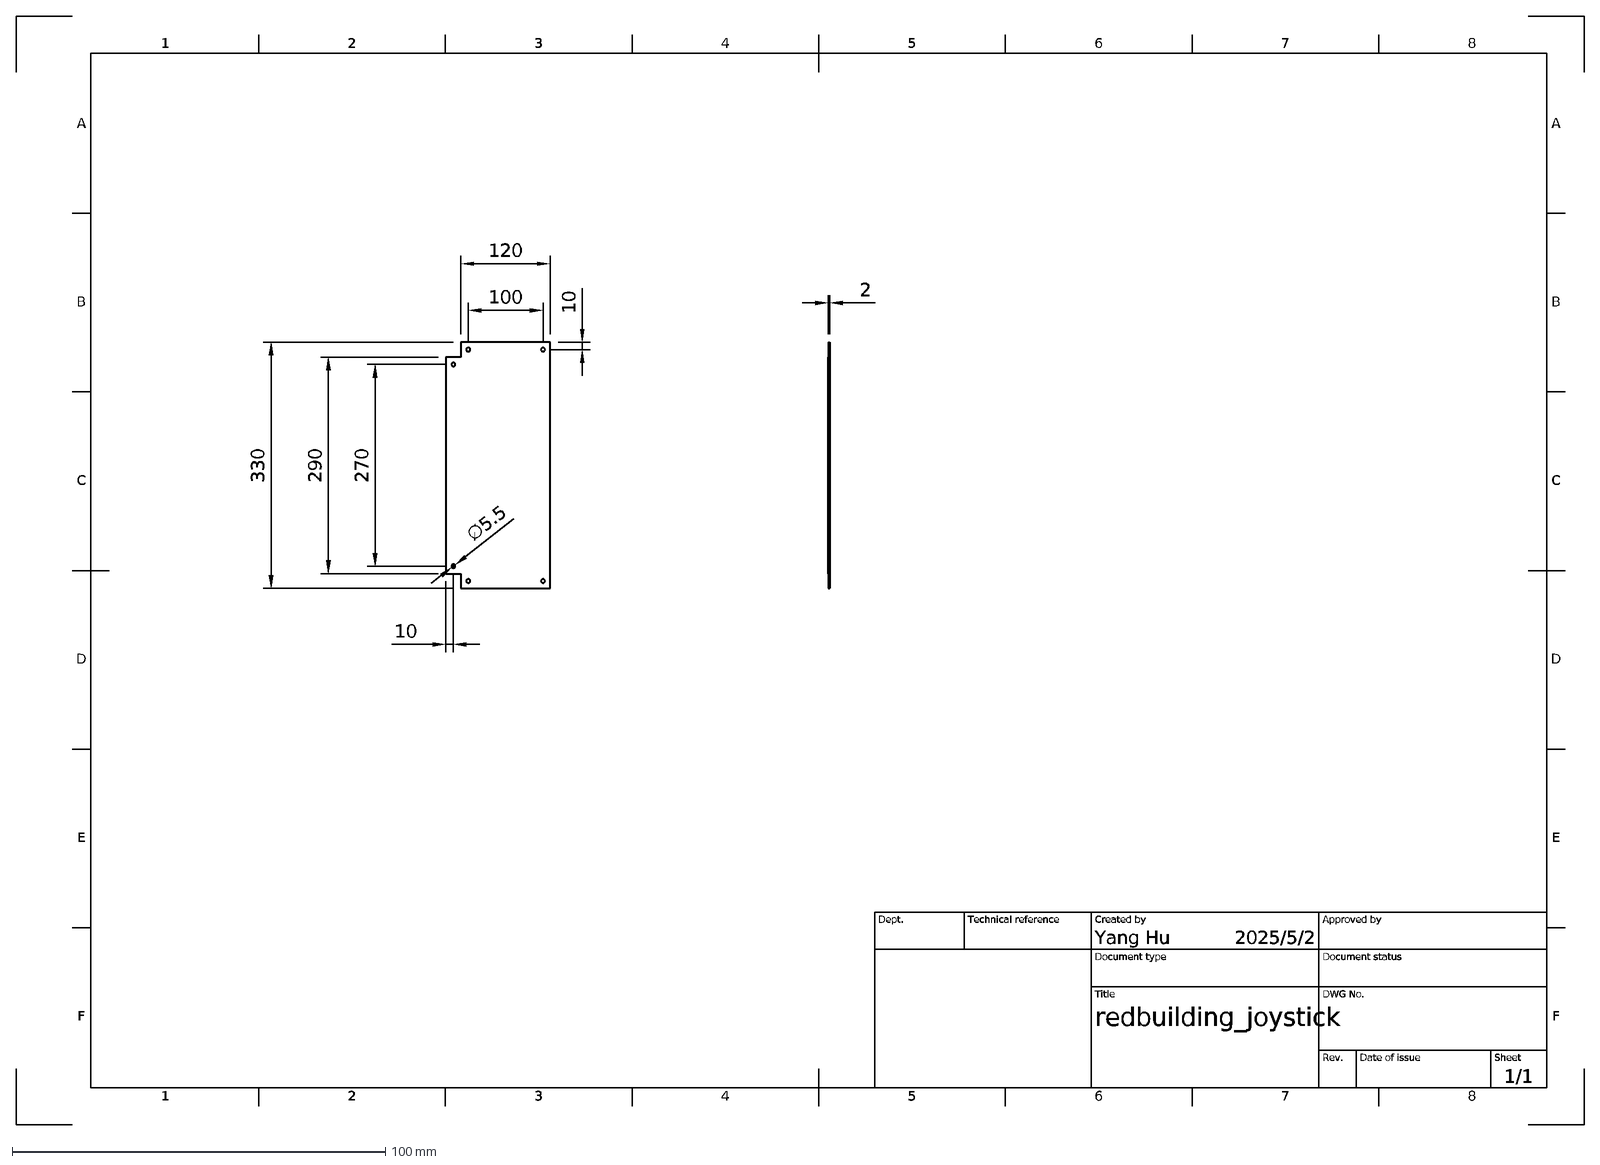
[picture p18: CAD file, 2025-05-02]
manufacture/plate/redbuilding/extra_top.dxf
1
A
2
3
4
5
6
7
8
B
C
D
E
F
2025/5/2
1/1
redbuilding_joystick
Yang Hu
Dept.
Technical reference
Created by
Approved by
Document type
Document status
Title
DWG No.
Rev.
Date of issue
Sheet
100
120
10
270
290
330
∅5.5

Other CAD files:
manufacture/plate/europe/core_top.dxf
manufacture/plate/redbuilding/core_top.dxf
manufacture/plate/europe/display.dxf
manufacture/plate/redbuilding/extra_side.dxf
manufacture/plate/europe/extra_top.dxf
manufacture/plate/redbuilding/display_holder.dxf
manufacture/plate/redbuilding/joystick_holder.dxf
manufacture/plate/redbuilding/redbuilding_joystick_holder.dxf

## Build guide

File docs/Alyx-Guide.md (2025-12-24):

# How to Use Alyx with CageLab

Alyx is an experiment database made by International Brain Lab. While alyx is mostly focused on neuroscience tasks in mice, it can be generalised to other species as it supports generic JSON fields, and the core structure across species is more similar that the differences anyway. We use TWO services:

* Alyx database — register subjects, labs, experimenters, projects and tasks; each time a session is run record the experiment metadata and link to the binary experiment files.
* AWS/S3 data store ([Minio](https://minio.org) server) — copy raw binary and text experiment files saved by each session linked to the Alyx session metadata. Searching in Alyx can recover the files saved in the S3 data store.

------

In the CageLab GUI there are two main interactions with Alyx:

1) Login / query the database. Not linked to an experiment session.
2) Setup session data and enable CageLbb to add the session to the database. THe session is added by the remote system, not the control computer.

# BEFORE STARTING: Setting up the Database

> [!IMPORTANT] 
> You **MUST** ensure the Alyx database is setup with the core items you will use to run the session: `Subjects`, `Users`, `Labs`, `Locations`, `Projects`

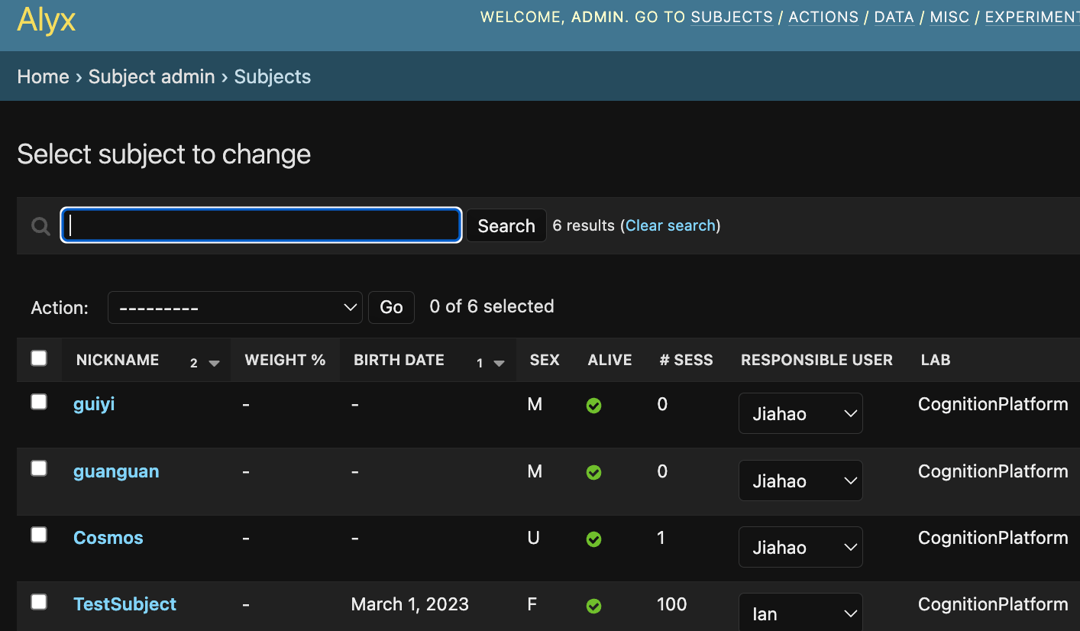
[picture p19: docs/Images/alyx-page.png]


Before running any sessions, ensure that the items you will use exist in the Alyx database, login to your Alyx web interface (e.g. http://172.16.102.30:8000 ) and edit the database to add the `Subjects`, the `Users` (Researcher), the `Lab`, and the `Projects` the sessions will be linked to.

# CageLab: (1) Logging in and running queries

CageLab allows you to enter your Alyx IP/port and user name and then login:

Alyx IP address

There is also a place to enter the Data repo IP and the data repo (bucket) name, and also to be able to edit the Alyx login password and data repo keys:

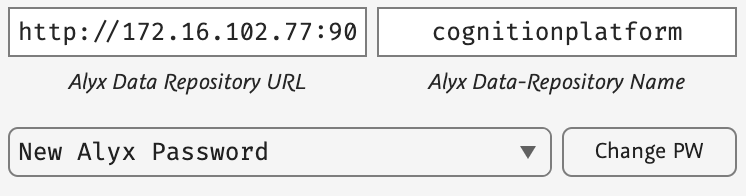
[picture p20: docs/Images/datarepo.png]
Data repo


> [!TIP]
> These details are stored using MATLAB's `getSecret` and `setSecret` functions and are stored on the local, not remote machine. The remote machine can be set up with its own secrets or when a session runs the local secrets are sent to the remote system at runtime.

Once logged in you will see the query panel become active:

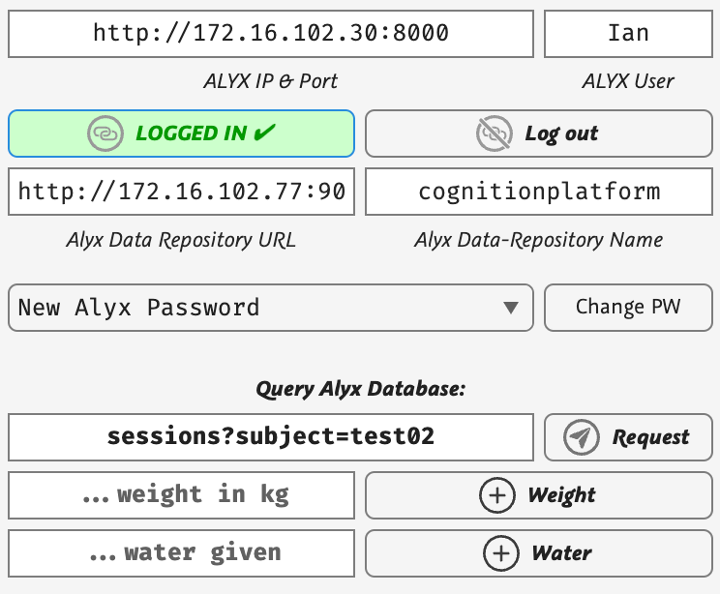
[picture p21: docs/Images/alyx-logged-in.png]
Logged In


Note that you are logged in from your computer. This is nothing to do with a remote cagelab. By logging in it allows you to run Alyx database queries, for example `sessions?subject=TestSubject` will return all sessions recorded by Alyx for subject `TestSubject`:  

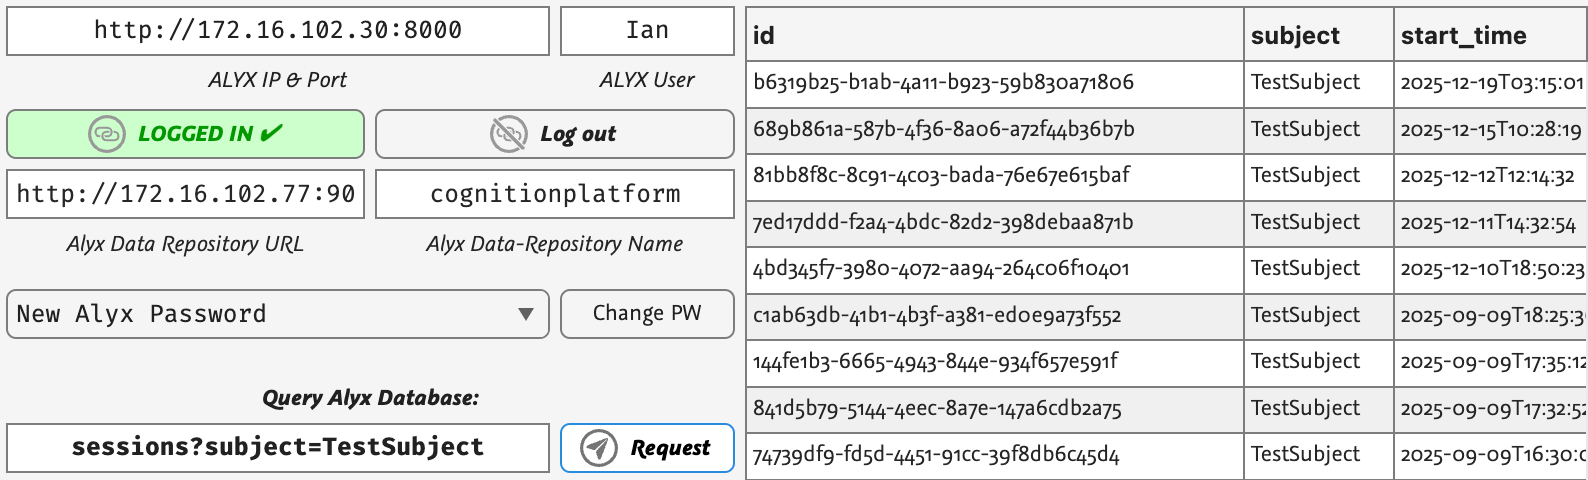
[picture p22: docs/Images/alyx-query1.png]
Query 1


... or for example the lab locations where experiments are run:

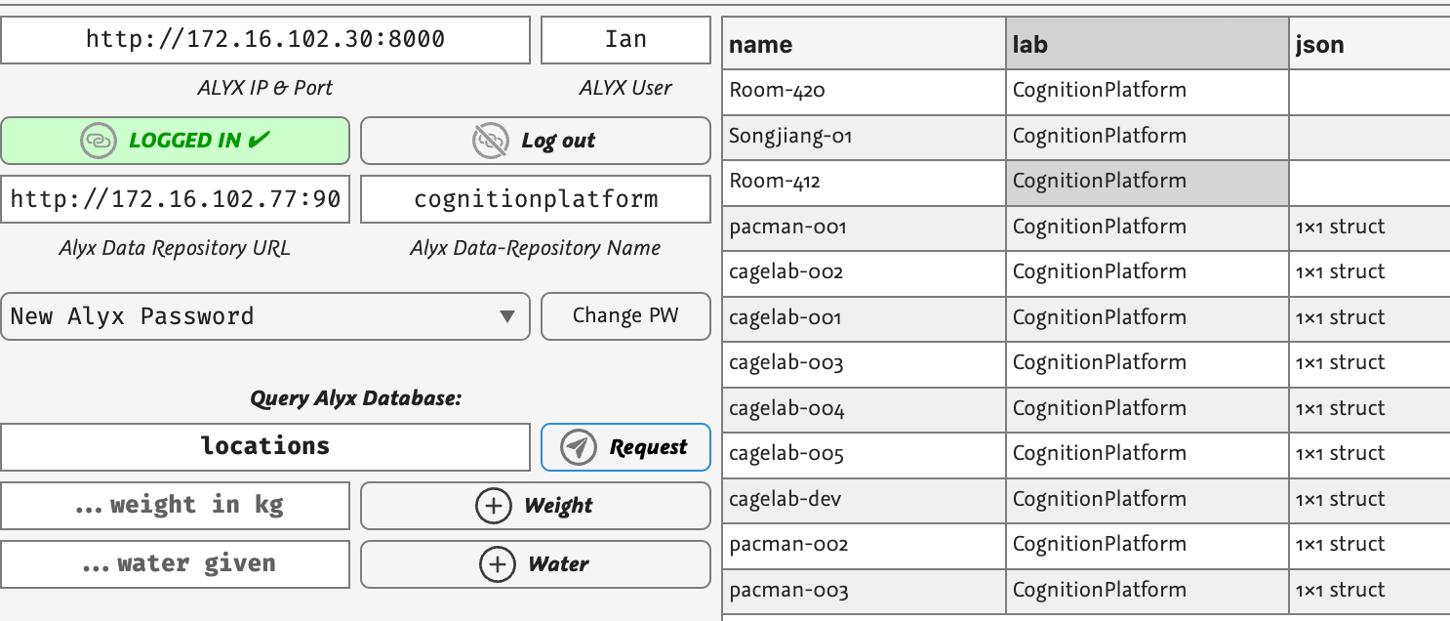
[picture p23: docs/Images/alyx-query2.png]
Query 2


A full list of all the queries you can perform is available from the Alyx database itself: http://172.16.102.30:8000/docs/ 

# CageLab: (2) Running a Session

Enable Alyx

When you use CageLab GUI, turn ON push to Alyx. You can also "initiate" Alyx at session start so that Alyx logs a session once it initiates (otherwise it will only register after it is manually ended, thus a crash would not show in Alyx and data be lost).

Then ensure your Session data is accurate and consistent with what is in the database:

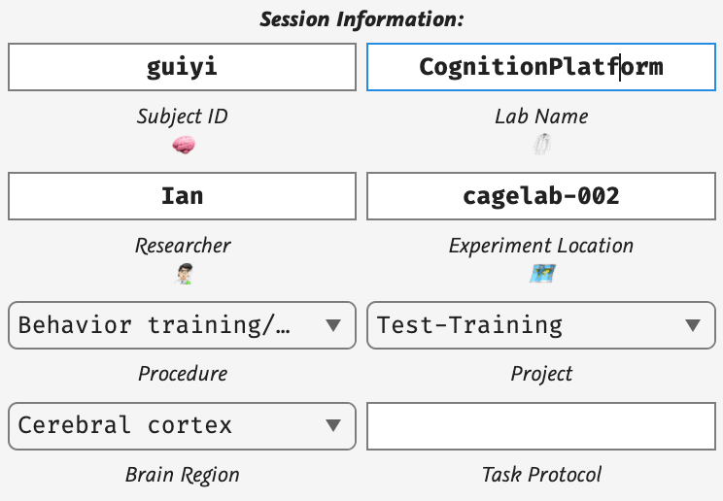
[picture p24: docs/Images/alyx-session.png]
Session


Subject, Lab, User and Location MUST already exist in Alyx or else it will crash. Procedure, Project, Brain Region should also be valid (they are populated after logging in to ensure they are valid). Task protocol is optional. 

When you run the task, Alyx will be initiated with a new Session, and when the session is stopped / ends, the MAT and LOG files will be uploaded to the S3 data server. You can check in the Sessions view:

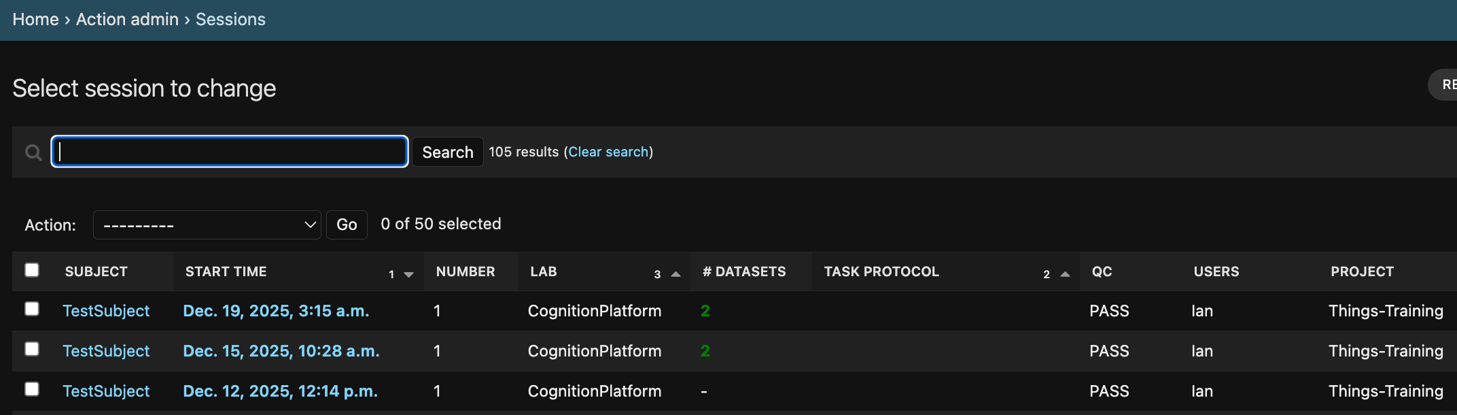
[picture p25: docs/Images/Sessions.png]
Sessions


You will see the session and can confirm that datasets were added. Note the data also remains in the same local SavedData folder, so it is available even if there is a database crash or other problem.

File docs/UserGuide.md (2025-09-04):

# User Guide for CageLab 

CageLab uses several core componenets to control and run remote neuroscience experiments, the cage-attached box is called **CageLab-Box** and the control computer **Control-PC**: 

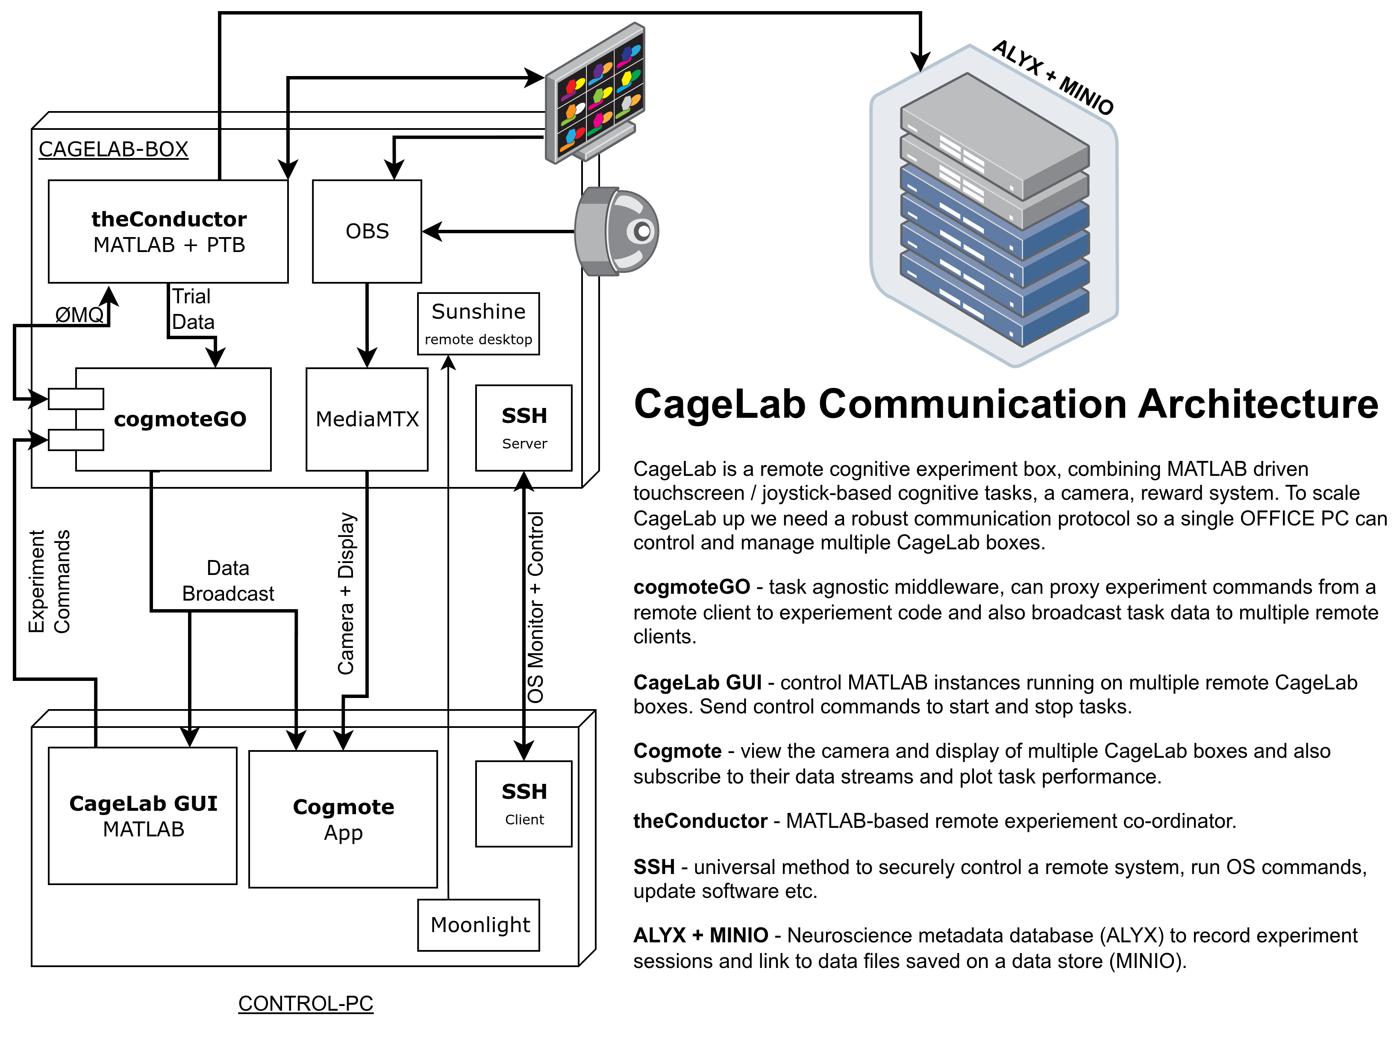
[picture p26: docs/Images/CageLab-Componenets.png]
Fig. 1 -- Main software componenets for Control and Communication


For the enduser, the important ones are **Cogmote**, **CageLab-GUI** and **SSH**. These 3 tools allow you to control and view the remote system. You can also use **Sunshine**/**Moonlight** as a remote-desktop GUI if needed.

## Cogmote

...

## CageLab-GUI

CageLab-GUI is a MATLAB tool to create a set of control options that can be sent to run experiments via cogmoteGO. We use PTB and opticka to manage most experiments, sending a structure of options to CageLab tasks. One CageLaB-GUI can connect to many remote CageLab-Box devices.

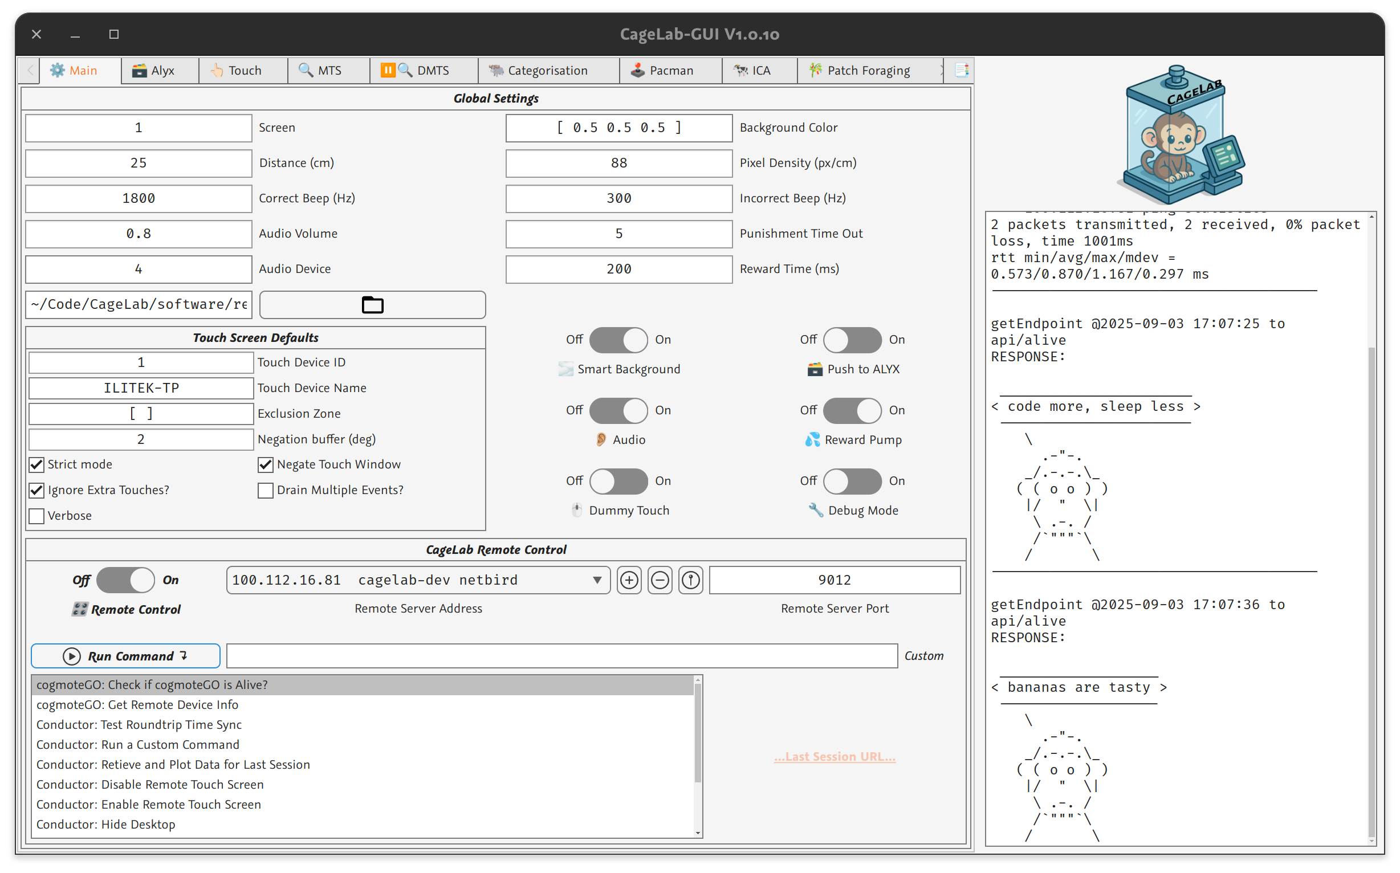
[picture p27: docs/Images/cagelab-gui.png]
Fig. 2 -- Main GUI to Control CageLab-Box experiments


## SSH Control

`ssh` allows you to login to the remote CageLab-Box and run commands and manage the system. You can also monitor the services that run on CageLab-Box. `ssh` uses private_public keys to ensure secure login. Each CageLab-Box has a public key, and the Control-PC has a private key stored in `~/.shh` that matches. To login you run the following command on the Control-PC:

```bash
ssh -i ~/.ssh/mykey cagelab@192.168.3.22.lab
```

You can simplify this by creating a `~/.ssh/config` file where you can specify the details for each system:

```conf
Host pacman-002
    Hostname 192.168.3.22
    User cagelab
    IdentityFile ~/.ssh/cagelab
	IdentitiesOnly yes
```

And now you can just type `ssh pacman-002` and the correct user and key will be used.  

All Linux commands are available. THe important commands involve managing the running services:

- `systemctl` - this manages services (`systemd` is the OS system that does this). For example to check the status of `cogmoteGO` you can run `systemctl --user status cogmoteGO`. To restart use the service: `systemctl --user restart cogmoteGO`
- `journalctl` - this command allows you to read the messages of a service. For example `journalctl --user --all -f -u theConductor` reads and follows the log for `theConductor`.

There are several zsh commands to help manage the remote system:

- `cagelab-reset` - restarts `cogmoteGO` and `theConductor`.
- `cagelab-monitor` - runs a CPU monitor, plus `journalctl` for both `cogmoteGO` and `theConductor` in 3 panel window. This uses a TMUX window (see below for the commands to control it).

### cagelab-monitor with tmux

You can remote view the logs of `cogmoteGO` and `theConductor` using `cagelab-monitor` once logged into ssh. This uses [tmux](https://github.com/tmux/tmux/wiki/Getting-Started) to divide the terminal window into 3 panes. You can enter a `tmux` control mode by pressing <kbd>ctrl</kbd><kbd>a</kbd>, then you can press <kbd>s</kbd> to show sessions. To exit the session press <kbd>x</kbd> and accept with <kbd>y</kbd>. You can open a new terminal in the session using <kbd>ctrl</kbd><kbd>a</kbd> then <kbd>-</kbd> or <kbd>ctrl</kbd><kbd>a</kbd> <kbd>|</kbd>.

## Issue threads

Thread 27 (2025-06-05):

theConductor should automatically exit after the failure of createProxy.

Ccccraz, 2025-06-05:
`theConductor` may start earlier than `cogmoteGO`. In this case, `createProxy` will time out, but `theConductor` will not exit, so it can not trigger systemd to restart automatically.

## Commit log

2025-04-16 docs: :memo: update README with power supply architectures (#2)
2025-04-18 docs: 📝 Added new cagelab overview (#3)
2025-05-02 feat: :sparkles: add redbuilding plate drawing
    [core_back.dxf, core_bottom.dxf, core_side.dxf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]
2025-05-02 feat: :sparkles: add europe standard plate drawing
    [core_back.dxf, core_side.dxf, display.dxf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]
2025-05-02 fix: :bug: add the missing drawings
    [core_bottom.dxf, core_top.dxf]
2025-05-02 fix: :bug: fix constraint markers
    [core_back.dxf, core_bottom.dxf, core_display.dxf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]
2025-05-02 feat: :sparkles: add bom for plate
    [bom.xlsx]
2025-06-05 fix: 🐛 add retry mechanism for HTTP requests in theConductor (#28)
2025-06-05 Revert "fix: 🐛 add retry mechanism for HTTP requests in theConductor (#28)" (#29)
    This reverts commit 19577ef931882e937822c1c0ebbdb9ee8fd37e62.
2025-06-05 fix: 🚑 remove clear all in theConductor service ExecStart (#30)
    * fix: 🐛 add retry mechanism and clear workspace in theConductor service
    * fix: :ambulance: remove clear all in theConductor service ExecStart
2025-06-09 fix: 🐛 Update input handling and initialization in task functions
2025-06-10 fix: 🐛 Update function signatures and logic in initialisation and trial result handling
2025-06-11 fix: 🐛 try to use 2024 to make GUI
2025-06-11 fix: 🐛 Update version number to 1.0.2
2025-06-13 fix: 🐛 Correct typo in version assignment in theConductor
2025-06-14 fix: 🐛 Update trial initialization and result handling in task functions
2025-06-16 fix: 🐛 Correct aspect ratio calculation in initialise function
2025-06-18 feat: :art: Add delayed match to sample
2025-07-08 fix: status buton now returns a single sample
2025-09-26 fix: only set performance power profile if present
2025-09-28 feat: :fire: push and pull from cagelab devices over local network using rsync and ssh
2025-10-10 feat: :fire: delayed non-match to sample updates
2025-10-11 [wip] refactor match to sample code
2025-11-14 docs: 📝 add some more comments
2025-11-14 fix: 🐛 typo for dataURL
2025-11-20 feat: :fire: touch phase 32+ adds a visual target to encourage finger release
2025-11-21 feat: 🎨 use unified staircase settings for training stages across tasks
2025-12-11 fix: :bug: stop button
